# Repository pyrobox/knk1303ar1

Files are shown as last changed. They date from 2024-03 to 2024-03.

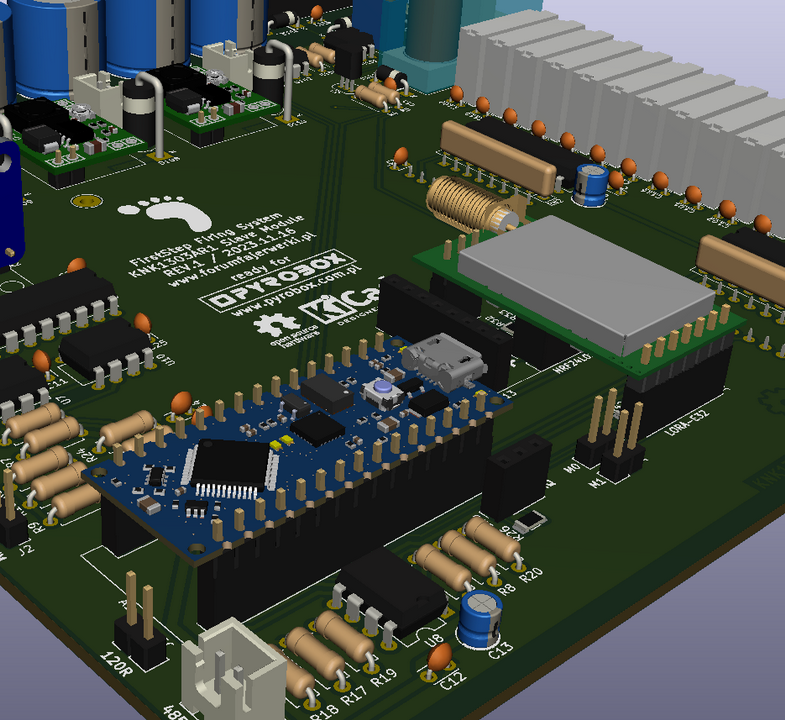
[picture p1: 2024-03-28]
img_20240310/KNK1303AR1_20240310_every_lora.png

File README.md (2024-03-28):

# KNK1303AR1

Project of firing module of amateur pyrotechnic system. 

## Description

For many years, the forum of fireworks enthusiasts https://forumfajerwerki.pl has been implementing projects of amateur pyrotechnic systems. 
KNK1303AR1 is another project, this time compatible with the professional Pyrobox pirotechnics system, based on the Arduino Nano Every board.
The design of the pcb was created in KiCad 7.0.8 and the code for Arduino Nano Every was written in Arduino IDE 2.3.2
This module is controlled by the free Pyrobox system software downloadable from https://www.pyrobox.com.pl/soft/downloads.html

## Help

You can find more information on the forumfajerwerki.pl in the thread 
https://www.forumfajerwerki.pl/topic/9585-forumowy-projekt-opensource-systemu-pirotechnicznego/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 
Forum registration is required.

A compendium of projects from the forumfajerwerki.pl
https://www.pyrobox.com.pl/knk1301/

## Authors

Zbigniew Kubicki (forumfajerwerki.pl nickname "zk1959")

## Version History

* Rev.1 as of 2024.03.10

## License

Open source hardware and freeware software.

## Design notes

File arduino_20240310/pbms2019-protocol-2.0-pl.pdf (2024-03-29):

PYROBOX Pyrotechnic Firing System | Data Transfer Protocol PBMS2019 Ver. 2.0

## PROTOKÓŁ TRANSMISJI DANYCH PBMS2019 Ver. 2.0

Protokół transmisji danych w systemie Pyrobox nie został z góry zaprojektowany lecz powstawał stopniowo (był poszerzany i modyfikowany z zachowaniem kompatybilności w dół) wraz z rozwojem systemu więc niektóre jego założenia i elementy są konsekwencją takiego właśnie procesu.

Sposób adresowania w systemie obwodów zapalczych (cue) także był modyfikowany i obecnie adresujemy je przez wskazanie kolejno:
G / group | zakres 1..16 | grupa urządzeń slave wykonujących określone (podobne) zadania
U / unit | zakres 1..16 | identyfikator urządzenia slave w grupie
M / module zakres 1..4 | numer modułu wykonawczego kontrolowanego przez urządzenie slave
S / section | zakres 1..16 | numer sekcji w module wykonawczym
C / channel zakres 1..16 | numer kanału w sekcji

Każdy program/kontroler master może więc nadzorować maksymalnie 16 grup urządzeń slave.
W każdej grupie może być maksymalnie 16 identyfikowanych urządzeń slave lub dowolna ich ilość jeśli zrezygnujemy z ich identyfikowania (co oznacza brak możliwości indywidualnego odwołania się do danego urządzenia np. zdalnego testowania obwodów zapalczych).
Każde urządzenie slave może nadzorować (obecnie) maksymalnie 4 moduły wykonawcze.
Moduł wykonawczy może mieć maksymalnie 16 sekcji, a każda sekcja ma 16 kanałów.
IP / max255 | G.U / max16.16 | M / max4 | S.C / max16.16

Urządzeniem slave może być:
- komputer z odpowiednim oprogramowaniem
- dedykowany konwerter np. konwerter/hab PB12CH4L1 obsługujący do 4 modułów
- moduł wykonawczy slave np. 32-kanałowy moduł SM032

Transmisja danych w sieci komunikacyjnej Pyrobox odbywa się w standardzie RS485. (https://pl.wikipedia.org/wiki/EIA-485)
Parametry transmisji: baudrate = 9600, bytesize = 8, parity = no, stopbits = 1, softflow = false, hardflow = false.
W transmisji mogą być wykorzystywane standardowe elementy sieci RS485 np. repeater, hub, radiomodem (transmisja przezroczysta).
Datasheet: pbms2019-protocol-2.0-pl.pdf | Page: 1 / 9

Master 1

Slave 1.2 | Section 1
Slave 1.1 | Module 1
| Module 2

Section 16

Master 2

Section 1

Section 16

PYROBOX Pyrotechnic Firing System | Data Transfer Protocol PBMS2019 Ver. 2.0

Dane przesyłane są w postaci ciągu znaków ASCII.
Ciąg znaków zawiera kolejno:
- znak „{” oznaczający początek pakietu danych (start)
- 4 znaki sumy kontrolnej CRC16 CCITT X-MODEM, oznaczane dalej jako <crc>
- 2 znaki literowe oznaczające komendę/rozkaz, dalej <cmd>
- 2 znaki z zakresu 00..FF wskazujące część adresu obwodu zapalczego Group.Unit , dalej <adr>
- 2 znaki z zakresu 00..03 wskazujące kolejną część adresu Module, dalej <mod>
- 2 znaki z zakresu 00..FF wskazujące kolejną część adresu Section.Channel, dalej <cue>
- n znaków danych sformatowanych w sposób przedstawiony w tabelach poniżej
- znak „}” oznaczający koniec pakietu (stop)
W przypadku niektórych komend część z wymienionych elementów ciągu nie jest wykorzystywana.

Komendy podzielone zostały na 3 grupy:
- grupa 1 - rozkazy kierowane jednocześnie do wszystkich urządzeń
- grupa 2 - rozkazy kierowane do jednego lub wszystkich urządzeń w grupie
- grupa 3 - rozkazy kierowane tylko do jednego urządzenia w grupie
Datasheet: pbms2019-protocol-2.0-pl.pdf | Page: 2 / 9

PYROBOX Pyrotechnic Firing System | PBMS2019 Data Transfer Protocol Ver. 2.0

GROUP 1 / All Units, part 1

COMMANDS: | 1 | 2 | 3 | 4 | 5 | 6 | 7 | 8 | 9 | 10 | 11 | chars | string | answer
MN Arm_On_All | { | <crc> | MN | } | | | | | | | | 8 | {D29AMN)
MN Arm_On_Unit_PBMS2019 | { | <crc> | MN | <adr> | } | | | | | | | 10
MF Arm_Off_All | { | <crc> | MF | } | | | | | | | | 8 | (5392MF}
MF Arm_Off_Unit_PBMS2019 | { | <crc> | MF | <adr> | } | | | | | | | 10
MR Reset_All | { | <crc> | MR | } | | | | | | | | 8 | {0127MR}
MR Reset_Unit_PBMS2019 | { | <crc> | MR | <adr> | } | | | | | | | 10
XP | HeartBeat | { | <crc> | XP | } | 8 | {DDE3XP}
XM Start (sfx: time) | { | <crc> | XM | } | | | | | | | | 8 | {1E7FXM}
XT | Message (sfx: txt=str) | { | <crc> | XT | <txt> | } | max29
FA | All_Slave_Units (sfx: all=xxx) | { | <crc> | FA | <all> | } | 11
MX SAM_Start_PBMS2019v2.0 | { | <crc> | MX | <hms> | } | | | | | | | 14
MY SAM_Stop_PBMS2019v2.0 | { | <crc> | MY | } | | | | | | | | 8 | {B04CMY}
MZ SAM_HeartBeat_PBMS2019v2.0 | { | <crc> | MZ | } | | | | | | | | 8 | {802FMZ}
WA Warning_Ready_PBMS2019v2.0 | { | <crc> | WA | } | | | | | | | | 8 | {CFCDWA}
WB Warning_Armed_PBMS2019v2.0 | { | <crc> | WB | } | | | | | | | | 8 | {FFAEWB}
WC Warning_Disarmed_PBMS2019v2.0 | { | <crc> | WC | } | | | | | | | | 8 | {EF8FWC}
WD Warning_Safe_PBMS2019v2.0 | { | <crc> | WD | } | | | | | | | | 8 | {9F68WD}
MN | uzbroić system / uzbroić urządzenie <adr>
MF | rozbroić system / rozbroić urządzenie <adr>
MR | zresetować system / zresetować urządzenie <adr>
XP | sygnał heartbeat
XM | sygnał start | → funkcja: time
XT | wiadomość tekstowa | → funkcja: txt=str | → <txt>max21 / x..z | ← x..z = max 21 chars
FA | wykonać zadanie xxx ze skryptu ASU | → funkcja: all=xxx | → <all>3 / xxx | ← xxx = 001...999 number
MX | sygnał start w trybie SAM | → <hms>6 / hhmmss | ← hh=00..23 „hour” / mm=00..59 „minute” / ss=00..59 „second”
MY | awaryjny sygnał stop w trybie SAM | → Death Man Switch
MZ | sygnał heartbeat w trybie SAM | → max every 4.5sec
WA | pokazać że urządzenie jest w gotowości / manual | → yellow signal ligth
WB | pokazać że urządzenie jest uzbrojone / auto 1sec after MN | → red signal light
WC | pokazać że urządzenie jest rozbrojone / auto 1sec after MF | → green signal light
WD | pokazać że urządzenie jest bezpieczne / manual | → blue signal light
Datasheet: pbms2019-protocol-2.0-pl.pdf | Page: 3 / 9

PYROBOX Pyrotechnic Firing System | PBMS2019 Data Transfer Protocol Ver. 2.0

GROUP 1 / All Units, part 2 PBMS2019

COMMANDS: | 1 | 2 | 3 | 4 | 5 | 6 | 7 | 8 | 9 | 10 | 11 | chars | string | answer
SERVICE MODE ONLY:
PS | Write_IDNO | { | <crc> | PS | <ser> | } | 17 | yes
PS | Write_IDNO_check | { | <crc> | PS | <ser> | } | 17
NORMAL MODE:
PX | Read_IDNO | { | <crc> | PX | } | 8 | {D542PX} | yes
PX | Read_IDNO_answer | { | <crc> | PX | <ser> | } | 17
PY | Read_USER | { | <crc> | PY | <ser> | } | 17 | yes
PY | Read_USER_answer | { | <crc> | PY | <ser> | <usr> | } | 26
PU Write_USER | { | <crc> | PU | <ser> | <usr> | } | | | | | | 26 | | yes
PU Write_USER_check | { | <crc> | PU | <ser> | <usr> | } | | | | | | 26
PZ | Read_ADDR | { | <crc> | PZ | <ser> | } | 17 | yes
PZ | Read_ADDR_answer | { | <crc> | PZ | <ser> | <add> | } | 23
PA | Write_ADDR | { | <crc> | PA | <ser> | <add> | } | 23 | yes
PA | Write_ADDR_check | { | <crc> | PA | <ser> | <add> | } | 23
PD Read_DATA | { | <crc> | PD | <ser> | } | | | | | | | 17 | | yes
PD Read_DATA_answer | { | <crc> | PD | <inf> | <pwr> | <ser> | <usr> | <add> <arm> | <ant> | } | max46
PS | zapisać numer seryjny urządzenia | → <ser>9 / xxxxyynnn | ← xxxx=ABcd „type” / yy=19..99 „year” / nnn=001..999 „ser#”
PX | przesłać numer seryjny urządzenia
PY | przesłać identyfikator urządzenia | → <usr>9 / xxxyyynnn | ← xxx=ABC „user” / yyy=ABC „tool” / nnn=001..999 „idn#”
PU | zapisać identyfikator urządzenia
PZ | przesłać adres konfiguracyjny urządzenia | → <add>6 / xgumsc | ← x=2..5 / g=0..F / u=0..F / m=0..3 / s=0..F / c=0,4,8,C
PA | zapisać adres konfiguracyjny urządzenia
PD | przesłać pełną informację nt. Urządzenia | → <inf>4 / xxxx | ← x=0,1,2,3,7,B,F number of sections 0,2,3,4,8,12,16
→ <pwr>6 / xxxyyy | ← xxx=000..360 pwr#1 inside / yyy=000..500 pwr#2 outside
→ <arm>1 / x = 0..3 | ← 0=safe / hard_arm=0/1 / soft_arm=0/2 / 3=armed
→ <ant>3 / xxx = 000..100 ← % RF signal power
Datasheet: pbms2019-protocol-2.0-pl.pdf | Page: 4 / 9

PYROBOX Pyrotechnic Firing System | PBMS2019 Data Transfer Protocol Ver. 2.0

GROUP 2 / All Or One Unit In Group

COMMANDS: | 1 | 2 | 3 | 4 | 5 | 6 | 7 | 8 | 9 | 10 | 11 | chars | string | answer
FC | Fire_Cue_G | { | <crc> | FC | <adr> <mod> <cue> | } | 14
FO Fire_Cue_U (sfx: one=nn) | { | <crc> | FO | <adr> <mod> <cue> <one> | } | 15
FP | Fire_Pulse_G (sfx: imp=xxx) | { | <crc> | FP | <adr> <mod> <cue> | <pls> | } | 17
FP | Fire_Pulse_U (sfx: imp=xxx/nn) | { | <crc> | FP | <adr> <mod> <cue> | <pls> | <one> | } | 18
FS | Regular_Sequencer_G (sfx: seq=aa/bb) | { | <crc> | FS | <adr> <mod> <cue> | <ssn> | <sst> | } | 18
FS | Regular_Sequencer_U (sfx: seq=aa/bb/nn) | { | <crc> | FS | <adr> <mod> <cue> | <ssn> | <sst> | <one> | } | 19
FH | Speed_Up_Sequencer_G (sfx: shi=aa/bb/cc) | { | <crc> | FH | <adr> <mod> <cue> | <ssn> | <sst> | <ssd> | } | 20
FH | Speed_Up_Sequencer_U (sfx: shi=aa/bb/cc/nn) | { | <crc> | FH | <adr> <mod> <cue> | <ssn> | <sst> | <ssd> <one> | } | 21
FL | Speed_Down_Sequencer_G (sfx: slo=aa/bb/cc) | { | <crc> | FL | <adr> <mod> <cue> | <ssn> | <sst> | <ssd> | } | 20
FL | Speed_Down_Sequencer_U (sfx: slo=aa/bb/cc/nn) | { | <crc> | FL | <adr> <mod> <cue> | <ssn> | <sst> | <ssd> <one> | } | 21
FT | Programming_Sequencer_G (sfx: sdf=xxx) | { | <crc> | FT | <adr> | <sdf> | } | 14
FT | Programming_Sequencer_U (sfx: sdf=xxx/nn) | { | <crc> | FT | <adr> | <sdf> | <one> | } | 14
FN | Zero_Delay_Firing_G (sfx: nxt=x, x=2..5) | { | <crc> | FN | <adr> <mod> <cue> | .. | <adr5> <mod5> <cue5> | } | max38
MS Set_Select_Cues_G (sfx: set=xxxxxxxx) | { | <crc> | MS | <adr> <mod> <set> | } | 20
MS Set_Select_Cues_U (sfx: set=xxxxxxxx/nn) | { | <crc> | MS | <adr> <mod> <set> | <one> | } | 21
FC | odpalić cue w grupie
FO | odpalić cue w urządzeniu <one> | → funkcja: one=nn | → <one>2 / nn = 01..16 unit#
FP | odpalić cue impulsem xxx | → funkcja: imp=xxx/nn | → <pls>3 / xxx = 100..900 msec ++ nn = 01..16 „one”
FS | uruchomić sekwencję | → funkcja: seq=aa/bb/nn | → <ssn>2 / aa = 02..99 ++ <sst>2 / bb = 02..99 ++ nn = 01..16 „one”
FH | uruchomić sekwencję step-up | → funkcja: shi=aa/bb/cc/nn | → <ssn>2 / aa = 02..99 ++ <sst>2 / bb = 02..99 ++ <ssd>2 / cc = 01..49 ++ nn = 01..16
FL | uruchomić sekwencję step-down | → funkcja: slo=aa/bb/cc/nn | → <ssn>2 / aa = 02..99 ++ <sst>2 / bb = 02..99 ++ <ssd>2 / cc = 01..49 ++ nn = 01..16
FT | uruchomić sekwencję ze skryptu SDF | → funkcja: sdf=xxx/nn | → <sdf>3 / xxx = 001..999 ++ nn = 01..16 „one”
FN | odpalić x cue w grupie | → funkcja: nxt=x | → x = 2..5 repeats <adr><mod><cue>
MS | włączyć y cue w urządzeniu | → funkcja: set=xxxxxxxx/nn → <set>8 / xxxxxxxx = 00000000..FFFFFFFF ++ nn = 01..16 „one”
Datasheet: pbms2019-protocol-2.0-pl.pdf | Page: 5 / 9

PYROBOX Pyrotechnic Firing System | PBMS2019 Data Transfer Protocol Ver. 2.0

GROUP 3 / One Unit In Group, part 1

COMMANDS: | 1 | 2 | 3 | 4 | 5 | 6 | 7 | 8 | 9 | 10 | 11 | chars | string | answer
XY | Master_Slave_Link_Test | { | <crc> | XY | <adr> | } | 10 | yes
XY | MSLT_answer | { | <crc> | XY | <adr> | <inf> | <pwr> | } | 14/20
XY | MSLT_answer_PBMS2019 | { | <crc> | YX | <adr> | <ser> | } | 19
YX | Slave_Master_Link_Test | { | <crc> | YX | <adr> | } | 10 | yes
YX | SMLT_answer | { | <crc> | YX | <adr> | } | 10
YX | Slave_Master_Link_Test_PBMS2019 | { | <crc> | YX | <adr> | <ser> | } | 19 | yes
YX | SMLT_answer_PBMS2019 | { | <crc> | YX | <adr> | <ser> | } | 19
XZ | Master_Reserve_Link_Test | { | <crc> | XZ | } | 8 | {7CA9XZ} | yes
XZ | MRLT_answer | { | <crc> | XZ | } | 8 | {7CA9XZ}
XZ | MRLT_answer_PBMS2019 | { | <crc> | XZ | <ser> | } | 17
ZX | Reserve_Master_Link_Test | { | <crc> | ZX | } | 8 | {3A89ZX} | yes
ZX | RMLT_answer | { | <crc> | ZX | } | 8 | {3A89ZX}
ZX | RMLT_answer_PBMS2019 | { | <crc> | ZX | <ser> | } | 17
ZZ | Master_Reserve_Switch | { | <crc> | ZZ | } | 8 | (1ACBZZ}
XY | sprawdzić połączenie master → slave <adr>
YX | sprawdzić połączenie slave <adr> → master
XZ | sprawdzić połączenie master → master_reserve
ZX | sprawdzić połączenie master_reserve → master
ZZ | przekazać kontrolę master → reserve master
Datasheet: pbms2019-protocol-2.0-pl.pdf | Page: 6 / 9

PYROBOX Pyrotechnic Firing System | PBMS2019 Data Transfer Protocol Ver. 2.0

GROUP 3 / One Unit In Group, part 2 PBMS2019v2.0

COMMANDS: | 1 | 2 | 3 | 4 | 5 | 6 | 7 | 8 | 9 | 10 | 11 | chars | string | answer
XK Master_Keypad_Link_Test | { | <crc> | XK | } | | | | | | | | 8 | {7EB9XK} | yes
XK MKLT_answer | { | <crc> | XK | } | | | | | | | | 8 | {7EB9XK}
XK MKLT_answer_PBMS2019v2.0 | { | <crc> | XK | <ser> | } | | | | | | | 17
KX Keypad_Master_Link_Test | { | <crc> | KX | } | | | | | | | | 8 | {0ACBKX} | yes
KX KMLT_answer | { | <crc> | KX | } | | | | | | | | 8 | {0ACBKX}
KX KMLT_answer_PBM2019v2.0 | { | <crc> | KX | <ser> | } | | | | | | | 17
XV | Master_Starter_Link_Test | { | <crc> | XV | } | 8 | {DB25XV} | yes
XV | MSLT_answer | { | <crc> | XV | } | 8 | {DB25XV}
XV | MSLT_answer_PBMS2019v2.0 | { | <crc> | XV | <ser> | } | 17
VX | Starter_Master_Link_Test | { | <crc> | VX | } | 8 | {7FE4VX} | yes
VX | SMLT_answer | { | <crc> | VX | } | 8 | {7FE4VX}
VX | SMLT_answer_PBMS2019v2.0 | { | <crc> | VX | <ser> | } | 17
XK | sprawdzić połączenie master → keypad
KX | sprawdzić połączenie keypad → master
XV | sprawdzić połączenie master → starter
VX | sprawdzić połączenie starter → master
Datasheet: pbms2019-protocol-2.0-pl.pdf | Page: 7 / 9

PYROBOX Pyrotechnic Firing System | PBMS2019 Data Transfer Protocol Ver. 2.0

GROUP 3 / One Unit In Group, part 3

COMMANDS: | 1 | 2 | 3 | 4 | 5 | 6 | 7 | 8 | 9 | 10 | 11 | chars | string | answer
XA | Master_Player_Link_Test | { | <crc> | XA | } | 8 | {DFF3XA} | yes
XA | MPLT_answer | { | <crc> | XA | } | 8 | {DFF3XA}
XA | MPLT_answer_PBMS2019 | { | <crc> | XA | <ser> | } | 17
AX | Player_Master_Link_Test | { | <crc> | AX | } | 8 | {E500AX} | yes
AX | PMLT_answer | { | <crc> | AX | } | 8 | {E500AX}
AX | Player_Master_Link_Test_PBMS2019 | { | <crc> | AX | <ser> | } | 17 | yes
AX | PMLT_answer_PBMS2019 | { | <crc> | AX | <ser> | } | 17
XB | Master_Player_Reserve_Link_Test | { | <crc> | XB | } | 8 | {EF90XB} | yes
XB | MPRLT_answer | { | <crc> | XB | } | 8 | {EF90XB}
XB | MPRLT_answer_PBMS2019 | { | <crc> | XB | <ser> | } | 17
BX | Player_Reserve_Master_Link_Test | { | <crc> | BX | } | 8 | {B053BX} | yes
BX | PRMLT_answer | { | <crc> | BX | } | 8 | {B053BX}
BX | Player_Reserve_Master_Link_Test_PBMS2019 | { | <crc> | BX | <ser> | } | 17 | yes
BX | PRMLT_answer_PBMS2019 | { | <crc> | BX | <ser> | } | 17
XA | sprawdzić połączenie master → player
AX | sprawdzić połączenie player → master
XB | sprawdzić połączenie master → reserve player
BX | sprawdzić połączenie reserve player → master
Datasheet: pbms2019-protocol-2.0-pl.pdf | Page: 8 / 9

PYROBOX Pyrotechnic Firing System | PBMS2019 Data Transfer Protocol Ver. 2.0

GROUP 3 / One Unit In Group, part 4

COMMANDS: | 1 | 2 | 3 | 4 | 5 | 6 | 7 | 8 | 9 | 10 | 11 | chars | string | answer
TC | Test_Cue | { | <crc> | TC | <adr> <mod> <cue> | } | 14
TS | Test_Section | { | <crc> | TS | <adr> <mod> <cue> | } | 14
TM Test_Module | { | <crc> | TM | <adr> <mod> <cue> | } | 14
SC Send_Test_Cue | { | <crc> | SC | <adr> | } | | | | | | | 10 | | yes
SC STC_answer | { | <crc> | SC | <adr> | <0/1> | } | | | | | | 11
SS | Send_Test_Section | { | <crc> | SS | <adr> | } | 10 | yes
SS | STS_answer | { | <crc> | SS | <adr> | <tds> | } | 14
SM Send_Test_Module | { | <crc> | SM | <adr> | } | | | | | | | 10 | | yes
SM STM_answer | { | <crc> | SM | <adr> | <tdp> | <tdm> | } | | | | | 1..4x28
TC | wykonać test cue
TS | wykonać test całej sekcji
TM | wykonać test całego modułu
SC | przesłać wyniki testu cue | → <0/1>1 = 0/1
SS | przesłać wyniki testu sekcji | → <tds>4 = 0000..FFFF
SM | przesłać wyniki testu modułu | → <tdp>2 = 00..11 packet# / <tdm>16 = 0000000000000000..FFFFFFFFFFFFFFFF
Datasheet: pbms2019-protocol-2.0-pl.pdf | Page: 9 / 9

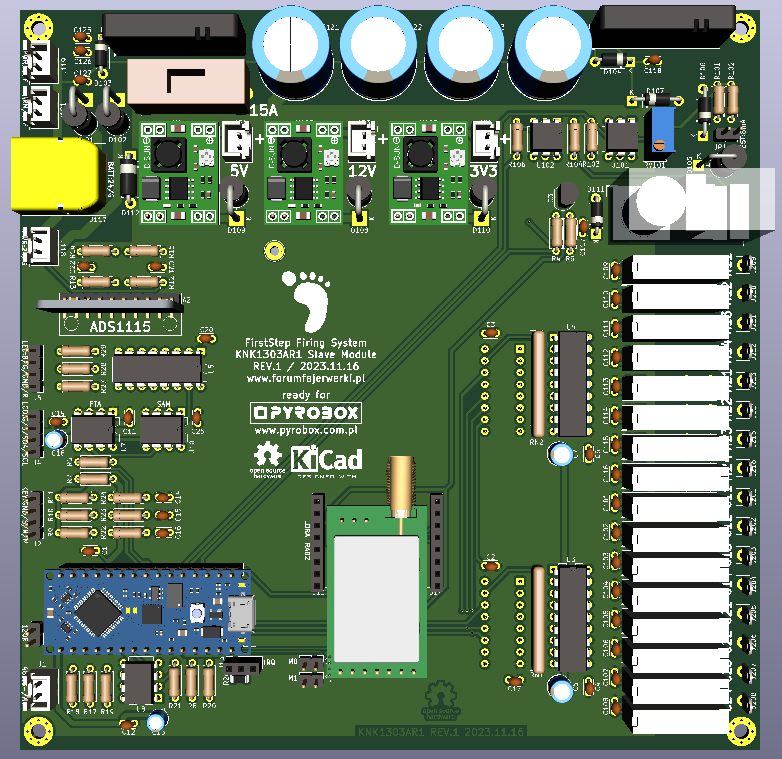
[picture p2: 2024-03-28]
img_20240310/KNK1303AR1_20240310_top.png

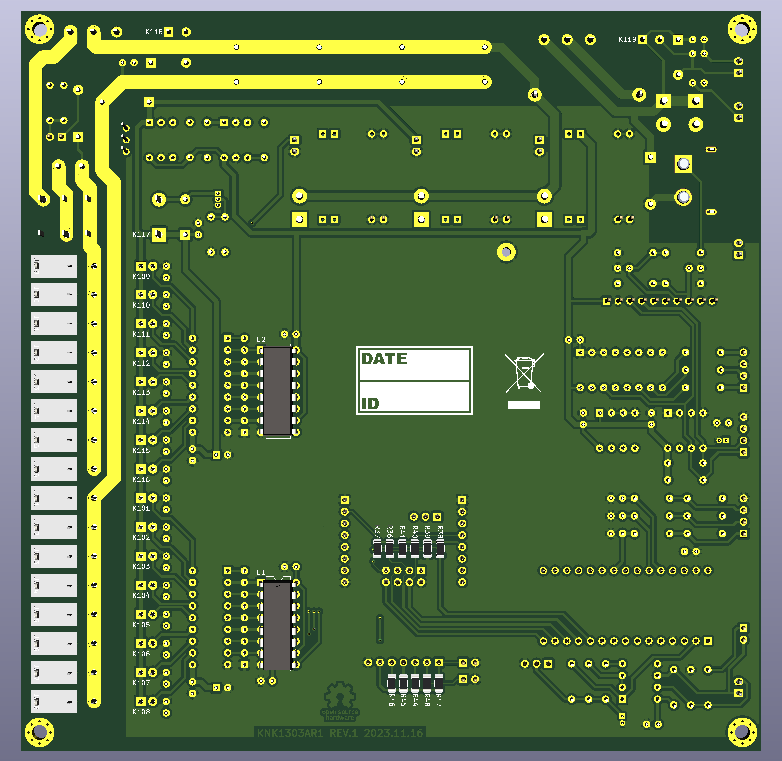
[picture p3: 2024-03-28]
img_20240310/KNK1303AR1_20240310_bottom.png

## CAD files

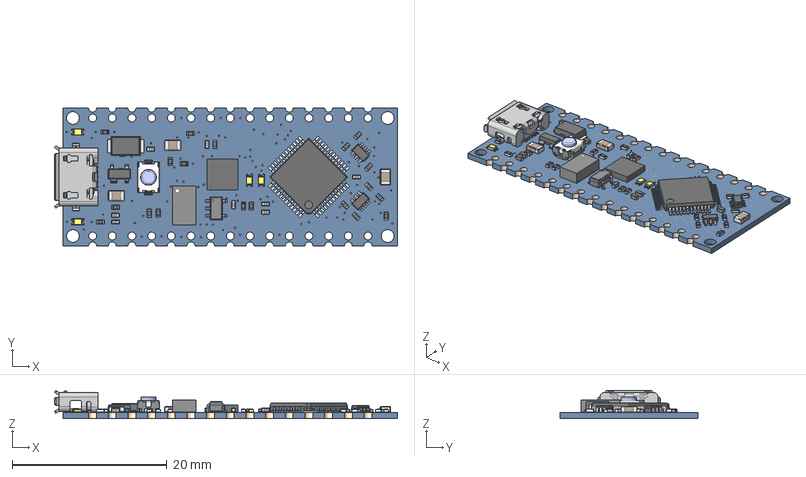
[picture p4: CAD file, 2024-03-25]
kicad_20240310/project_KNK1303AR1_3d/pyrobox_module_NANO_EVERY_v30.step
44.3 x 17.8 x 3.62 mm
Board
DNP x 19
22u x 3
PTS820
YELLOW x 4
MPM3610
AP2112K-3.3
ATSAMD11D14A
ATMEGA4809
ZX62-AB-5PA (1)
SOD128 Lead x 2
SOD128 Lower body x 2
SOD128 Upper body x 2
SOT143B lower body
SOT143B small Lead x 3
SOT143B Large lead
SOT143B Upper body
SOT353 Lower body x 2
SOT353 Lead x 12
SOT353 Upper body x 2
CAPC-0402-T0.55-BN v1 x 8

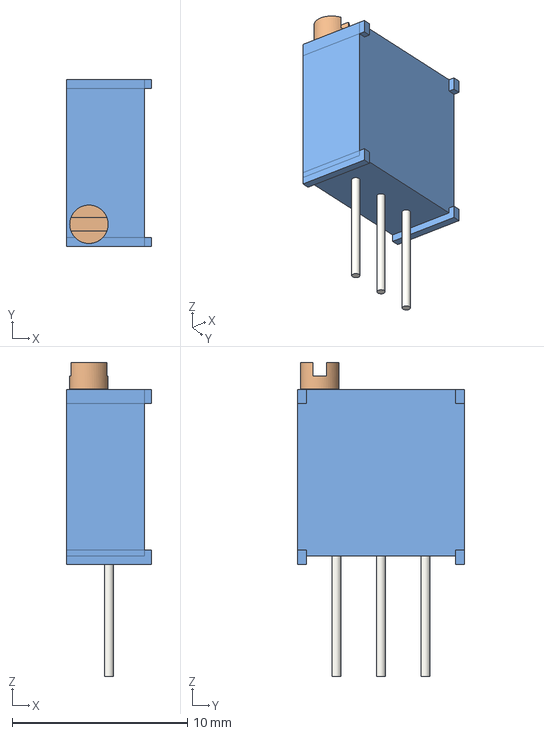
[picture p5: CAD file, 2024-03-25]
kicad_20240310/project_KNK1303AR1_3d/pyrobox_pcs_BOURNS-3296W.step
4.83 x 9.53 x 17.9 mm

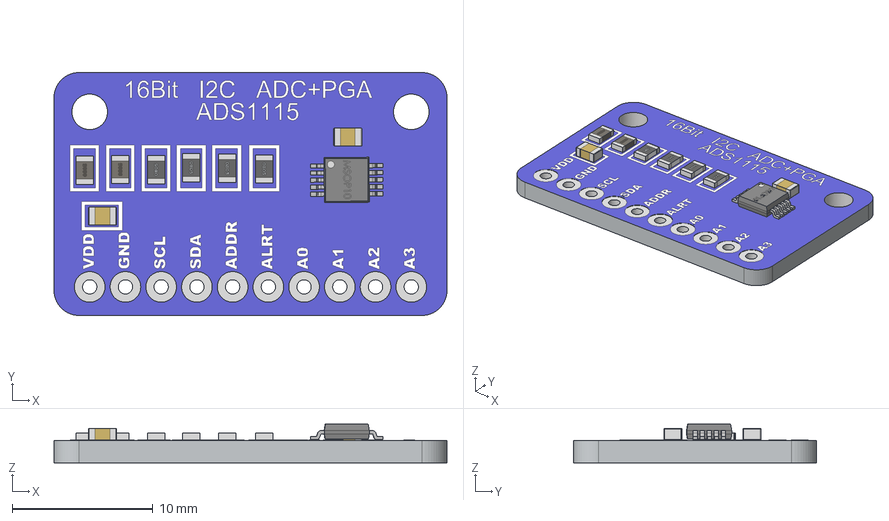
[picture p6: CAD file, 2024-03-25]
kicad_20240310/project_KNK1303AR1_3d/pyrobox_module_ADS1115.stp
27.9 x 17.3 x 2.74 mm
ADS1115
0805 Capacitor x 2
0805 Inductor x 2
0805 Resistor x 4
MSOP10

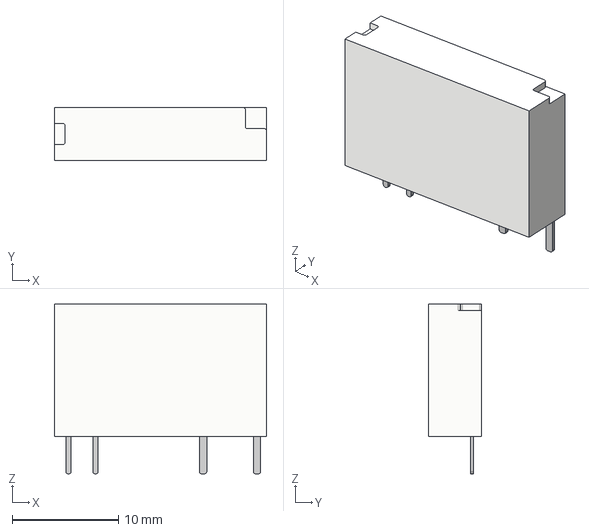
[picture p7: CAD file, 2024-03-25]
kicad_20240310/project_KNK1303AR1_3d/pyrobox_pcs_HONGFA_HF49FD-1H11T.step
20.0 x 5.00 x 16.0 mm

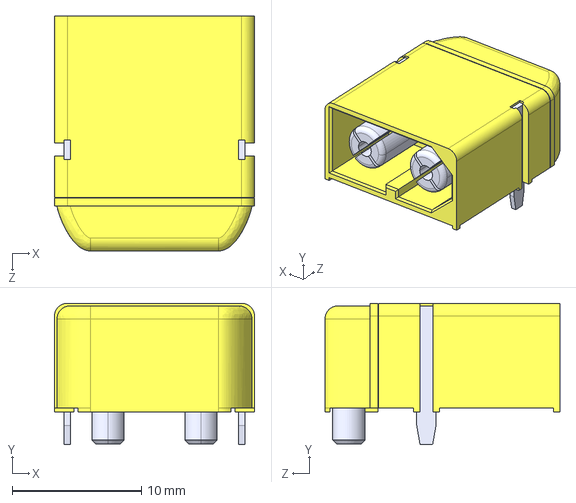
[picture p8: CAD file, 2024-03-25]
kicad_20240310/project_KNK1303AR1_3d/pyrobox_pcs_AMASS_XT60PW-M.step
15.5 x 11.0 x 18.2 mm

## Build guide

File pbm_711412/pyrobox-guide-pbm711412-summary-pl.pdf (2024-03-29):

PYROBOX Pyrotechnic Firing System | USER GUIDE | Pyrobox Controller MS Master PBM

Pyrobox Controller MS Master PBM Copyright © 2004-2024 Zbigniew Kubicki Pyrobox Pyrotechnic Firing System Copyright © 1994-2024 Zbigniew Kubicki

## Pyrobox Controller MS Master PBM, Version 7.1.1.412 USER GUIDE (summary)

Copyright © 2023-2024 Zbigniew Kubicki (Grupa PSO | K&K System)

## SPIS TREŚCI

Formatka Main | . | . | . | . | . | . | . | . | . | . | . | . | . | . | strona 2
Formatka Info+Update | . | . | . | . | . | . | . | . | . | . | . | strona 2

### A. SETUP

A1. Formatka SETUP . | . | . | . | . | . | . | . | . | . | . | . | . | . | strona 3
Grupa Access | . | . | . | . | . | . | . | . | . | . | . | . | . | strona 3
Grupa NET Starter | . | . | . | . | . | . | . | . | . | . | . | . | strona 3
Grupa DMX Starter | . | . | . | . | . | . | . | . | . | . | . | . | strona 4
Grupa OS Date/Time | SAM Mode . | . | . | . | . | . | . | . | . | strona 4
A2. Formatka NETWORK . | . | . | . | . | . | . | . | . | . | . | . | . | strona 4
Formatka DEVICE SETUP . | . | . | . | . | . | . | . | . | . | . | strona 5
Formatka NETWORK MONITOR | . | . | . | . | . | . | . | . | . | strona 5
Formatka MONITOR . | . | . | . | . | . | . | . | . | . | . | . | strona 6
A3. Formatka TESTER | . | . | . | . | . | . | . | . | . | . | . | . | . | strona 6
Formatka Test Result . | . | . | . | . | . | . | . | . | . | . | . | strona 7

### B. AUTO CONTROL

B1. Formatka EDITOR | . | . | . | . | . | . | . | . | . | . | . | . | . | strona 8
Formatka SPECIAL FUNCTIONS | . | . | . | . | . | . | . | . | . | strona 9
Funkcje specjalne | . | . | . | . | . | . | . | . | . | . | . | . | strona 9
Formatka SAM SCRIPT GENERATOR . | . | . | . | . | . | . | . | strona 10
B2. Formatka PLAYER | . | . | . | . | . | . | . | . | . | . | . | . | . | strona 10
B3. Formatka STEPPER . | . | . | . | . | . | . | . | . | . | . | . | . | strona 11
Formatka DELAY | . | . | . | . | . | . | . | . | . | . | . | . | strona 11
Formatka RESERVE . | . | . | . | . | . | . | . | . | . | . | . | strona 11
Formatka EXPLO X2 WAVE FLAMER Setup | . | . | . | . | . | . | strona 12
Formatka SAM Setup . | . | . | . | . | . | . | . | . | . | . | . | strona 12

### C. MANUAL CONTROL

C1. Formatka PBM | . | . | . | . | . | . | . | . | . | . | . | . | . | . | strona 13
C2. Formatka PBM STAGE | . | . | . | . | . | . | . | . | . | . | . | . | strona 13
Formatka PBM STAGE SETUP | . | . | . | . | . | . | . | . | . | strona 14
C3. Formatka DMX | . | . | . | . | . | . | . | . | . | . | . | . | . | . | strona 14
C4. Formatka DMX STAGE | . | . | . | . | . | . | . | . | . | . | . | . | strona 15
Formatka DMX STAGE SETUP | . | . | . | . | . | . | . | . | . | strona 15

### D. FIRST STEPS

D1. Instalacja i konfiguracja programu | . | . | . | . | . | . | . | . | . | . | strona 16
D2. Przygotowania i realizacja widowiska | . | . | . | . | . | . | . | . | . | strona 16
D3. Podpowiedzi i pomoce | . | . | . | . | . | . | . | . | . | . | . | . | strona 17
D4. System rozległy Pyrobox | . | . | . | . | . | . | . | . | . | . | . | . | strona 18
Datasheet: pyrobox-guide-pbm711412-summary-pl.pdf | Page: 1 / 18

### Formatka MAIN

1. Logo PYROBOX – kliknięcie otwiera formatkę INFO+UPDATE
2. Kontrolka Heart – sygnalizuje wysłanie/odebranie z sieci systemu sygnału „heartbeat”
3. Kontrolka PC – sygnalizuje odebranie z sieci NET systemu sygnału „ping”
4. Przycisk Setup – otwiera/zamyka formatkę SETUP
5. Przycisk Network – otwiera/zamyka formatkę NETWORK
6. Przycisk Tester – otwiera/zamyka formatkę TESTER
7. Przycisk Stepper – otwiera/zamyka formatkę STEPPER
8. Przycisk Player – otwiera/zamyka formatkę PLAYER
9. Przycisk Editor – otwiera/zamyka formatkę EDITOR
10. Przycisk DMX – otwiera/zamyka formatkę DMX
11. Przycisk DMX Stage – otwiera/zamyka formatkę DMX STAGE
12. Przycisk PBM – otwiera/zamyka formatkę PBM
13. Przycisk PBM Stage – otwiera/zamyka formatkę PBM STAGE
14. Przycisk Power – zamyka aplikację
15. Dolna belka formatki – po lewej wyświetla datę i czas, na środku i po prawej komunikaty
16. Formatka INFO+UPDATE
- przycisk Update – uruchamia procedurę pobierania aktualizacji programu

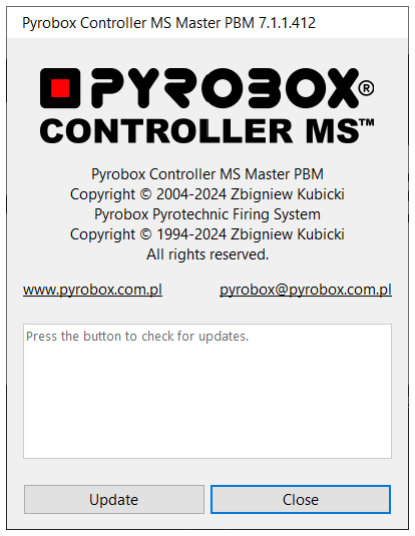
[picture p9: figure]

Uwaga!
Ogólne zasady pracy z programem Pyrobox Controller MS Master PBM zostały opisane w części D na stronie 16
Datasheet: pyrobox-guide-pbm711412-summary-pl.pdf | Page: 2 / 18

## A. SETUP

### A1. Formatka SETUP

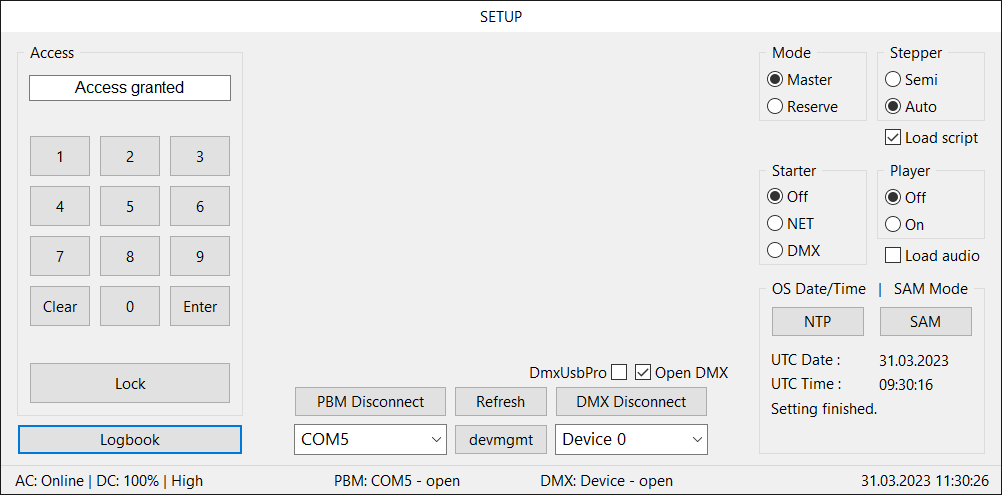
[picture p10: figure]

1. Grupa Access – służy do wprowadzania kodu dostępu, aktywuje krytyczne funkcje programu
- standardowy kod to "1234", zmieniamy go wprowadzając 4 cyfry starego i 4 cyfry nowego kodu
- przyciski 0..9, Clear oraz Enter spełniają standardowe funkcje
- przycisk Lock – anuluje uzyskaną autoryzację, ogranicza dostęp do krytycznych funkcji programu
2. Przycisk Logbook(Access) – przełącza widok pomiędzy grupami Access i Logbook
3. Grupa Logbook – udostępnia podgląd rejestru wykonanych czynności, oraz rejestrów wysłanych i odebranych komend/informacji
- przycisk Next – przełącza rejestry
- przycisk Open – otwiera folder zapisanych rejestrów
4. Przycisk PBM Connect/Disconnect + lista wyboru – włącza/wyłącza port PBM (USB/RS485)
5. Przycisk DMX Connect/Disconnect + lista wyboru – włącza/wyłącza port DMX (USB/DMX512)
6. Klucz DmxPro – włącza obsługę konwertera typu DMX USB PRO, a wyłącza OPEN USB DMX
7. Klucz Open DMX – włącza/wyłącza automatyczne otwieranie portu DMX
8. Przycisk Refresh – aktualizuje listy wyboru portów PBM, DMX oraz DMX Sterter
9. Przycisk devmgmt – otwiera formatkę systemową „Menadżer urządzeń”
10. Grupa Mode – ustawia tryb pracy programu: Master lub Reserve
11. Grupa Stepper – ustawia tryb pracy Steppera: Semi lub Auto
12. Klucz Load script – włącza/wyłącza automatyczne ładowanie skryptu do Steppera
13. Grupa Player – dołącza/odłącza Playera od Steppera
14. Klucz Load audio – włącza/wyłącza automatyczne ładowanie pliku audio do Playera
15. Grupa Starter – wyświetla odpowiednio grupy NET Starter lub DMX Starter
16. dolna belka – po lewej wyświetlana jest informacja o zasilaniu komputera, na środku o portach COM PBM i DMX, a po prawej data/czas
17. Grupa NET Starter – przechwytuje sygnał startu wysłany z serwera „NET Starter” pracującego w „prywatnej” sieci LAN np. Hamachi (aplikacja VPN - Virtual Private Network)
Datasheet: pyrobox-guide-pbm711412-summary-pl.pdf | Page: 3 / 18

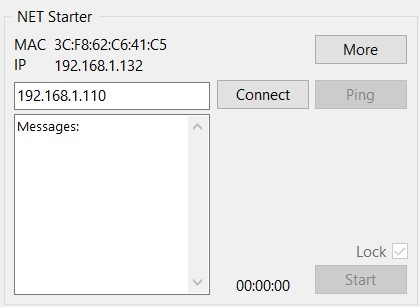
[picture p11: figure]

- etykieta MAC – adres sprzętowy karty sieciowej komputera
- etykieta IP – adres sieciowy komputera
- przycisk More – pobiera z komputera i wyświetla informacje „Primary Adapter Info”
- pole edycji Server – zawiera adres sieciowy serwera „NET Starter”
- przycisk Connect – nawiązuje połączenie z serwerem „NET Starter”
- przycisk Ping – wysyła ping do serwera „NET Starter” (test połączenia)
- przycisk Start – uruchamia NET Starter (oczekiwanie na komendę „start”)
18. Grupa DMX Starter – przechwytuje ustalony sygnał startu wysłany z kontrolera DMX lub innego (np. Art-Net) z konwersją transmisji na standard DMX
- pole wyboru Address – ustawia adres pierwszego z czterech kolejnych kanałów „triggera”
- pola wyboru Value – ustawiają wartości kanałów, a klucze dołączają kanały do „triggera”
- przycisk Connect/Disconnect + lista wyboru – włącza/wyłącza port DMX (USB/DMX512)
- przycisk Start – uruchamia DMX Starter (oczekiwanie na komendę „start”)

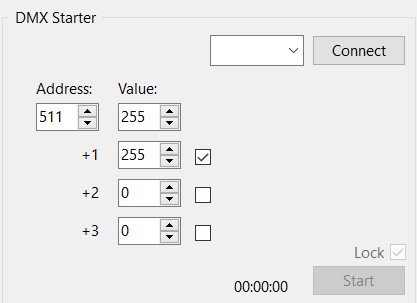
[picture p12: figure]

19. Grupa OS Date/Time | SAM Mode – obsługa trybu pracy SAM (Slave Autonomic Mode)
- przycisk NTP – uruchamia proces synchronizacji czasu systemowego komputera z serwerem NTP (Network Time Protocol) co jest niezbędne do pracy systemu w trybie SAM
- przycisk SAM – otwiera/zamyka formatkę SAM Setup opisaną na stronie 12

### A2. Formatka NETWORK

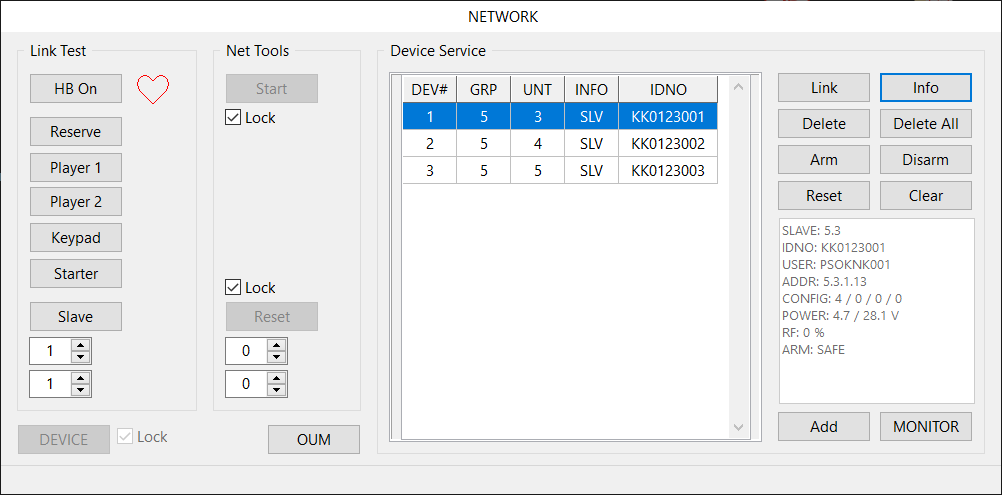
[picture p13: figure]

1. Grupa Link Test – umożliwia kontrolę pracy sieci systemu
- przycisk HB On – włącza/wyłącza sygnał „heartbeat”
- kontrolka Heart – sygnalizuje generowany sygnał „heartbeat”
- przycisk Reserve – testuje połączenie z Master-Reserve
- przycisk Player 1 - testuje połączenie z Player
- przycisk Player 2 - testuje połączenie z Player-Reserve
- przycisk Keypad – testuje połączenie z Master-Keypad
- przycisk Starter – testuje połączenie z Starter
- przycisk Slave - testuje połączenia z urządzeniem o adresie jak w polach wyboru (group+unit)
Datasheet: pyrobox-guide-pbm711412-summary-pl.pdf | Page: 4 / 18

2. Grupa Net Tools – pozwala wysyłać systemowe komendy:
- przycisk Start – wysyła komendę „start”
- przycisk Reset – wysyła komendę „reset” do urządzenia o adresie jak w polach wyboru (group+unit), 0 oznacza wszystkie grupy/jednostki
3. Grupa Device Service – służy do kontroli pracy urządzeń w sieci systemu
Uwaga! część z funkcji w tej grupie realizują wyłącznie urządzenia obsługujące protokół PBMS2019 Aby użyć której z funkcji należy uprzednio wybrać urządzenie (wiersz).
- przycisk Link - testuje połączenie z wybranym urządzeniem
- przycisk Info – pobiera z urządzenia informacje i wyświetla je w oknie Info
- przycisk Delete – usuwa z arkusza wskazany wiersz
- przycisk Delete All – usuwa z arkusza wszystkie wiersze
- przycisk Arm – wysyła komendę „arm” do wybranego urządzenia
- przycisk Disarm - wysyła komendę „disarm” do wybranego urządzenia
- przycisk Reset - wysyła komendę „reset” do wybranego urządzenia
- przycisk Clear – czyści okno Info
- arkusz - zawiera informacje o urządzeniach, które logowały się do kontrolera Master:
- kolumna DEV# - numer wiersza
- kolumna GRP – adres Group urządzenia
- kolumna UNT – adres Unit urządzenia
- kolumna INFO – identyfikator urządzenia:
RES – master-reserve / PLY – player / PLY2 – player-reserve / KEY – keypad / STR – starter / SLV – moduł slave
- kolumna IDNO – numer seryjny urządzenia
4. Przycisk DEVICE – otwiera formatkę Device Setup
5. Formatka DEVICE SETUP – umożliwia obsługę serwisową urządzeń

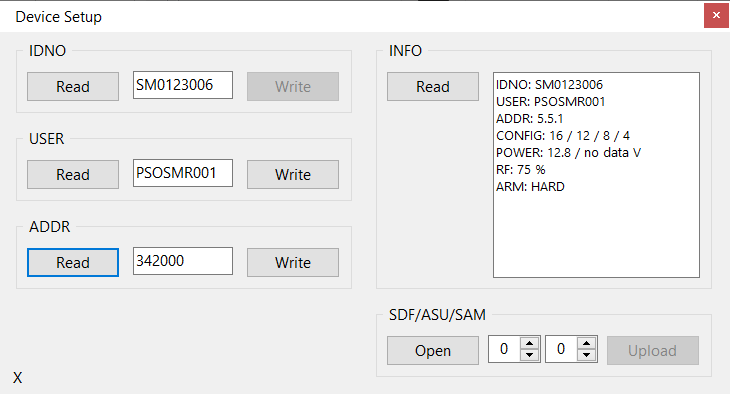
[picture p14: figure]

- grupa IDNO – umożliwia odczyt/zapis numeru seryjnego danego modułu, kliknij w pole edycji
- grupa USER - umożliwia odczyt/zapis oznaczenia danego modułu nadanego przez użytkownika
- grupa ADDR - umożliwia odczyt/zapis adresu slave danego modułu, kod do zapisu danych to „9876”
- grupa INFO - umożliwia odczyt informacji na temat danego modułu/urządzenia
- grupa SDF/ADU/SAM – umożliwia załadowanie skryptu SDF/ASU/SAM do wskzanego urządzenia
6. Przycisk Add – dodaje wskazne urządzenia do listy w Network Monitor
7. Przycisk MONITOR – otwiera formatkę Network Monitor
8. Formatka NETWORK MONITOR – pozwala nadzorować urządzenia pracujące w systemie
Aby użyć któreś z dostępnych funkcji należy uprzednio wybrać urządzenie (wiersz).
- przycisk Check All – pobiera dane z wszystkich urządzeń na liście
- przycisk Check – pobiera dane ze wskazanego urządzenia
- przycisk Delete All – usuwa z listy wszystkie urządzenia
- przycisk Delete – usuwa z listy wskazane urządzenie
- arkusz Devices - zawiera informacje o monitorowanych urządzeniach:
- kolumna DEV# - numer wiersza
- kolumna GRP – adres Group urządzenia
- kolumna UNT – adres Unit urządzenia
- kolumna INFO – identyfikator urządzenia:
RES – master-reserve / PLY – player / PLY2 – player-reserve / KEY – keypad / STR – starter / SLV – moduł slave
Datasheet: pyrobox-guide-pbm711412-summary-pl.pdf | Page: 5 / 18

- kolumna IDNO – fabryczny numer seryjny urządzenia
- kolumna USER – oznaczenie urządzenia nadane mu przez użytkownika
- kolumna CFG – konfiguracja wyjść urządzenia według klucza:
moduł#1 / moduł#2 / moduł#3 / moduł#4
liczba oznacza liczbę sekcji w module,
0 oznacza że moduł nie jest obsługiwany przez slave
- kolumna B1 – napięcie akumulatora nr 1 (wewnętrznego)
- kolumna B2 - napięcie akumulatora nr 2 (zewnętrznego)
- kolumna RF – poziom sygnału radiowego w %
- kolumna ARM – urządzenie:
SAFE – bezpieczne
H+ - kluczyk w pozycji ARM
S+ - uzbrojone przez Master
ARM – w pełni uzbrojone
- kolumna LT – informacja o wyniku Link Test: OK / ERR

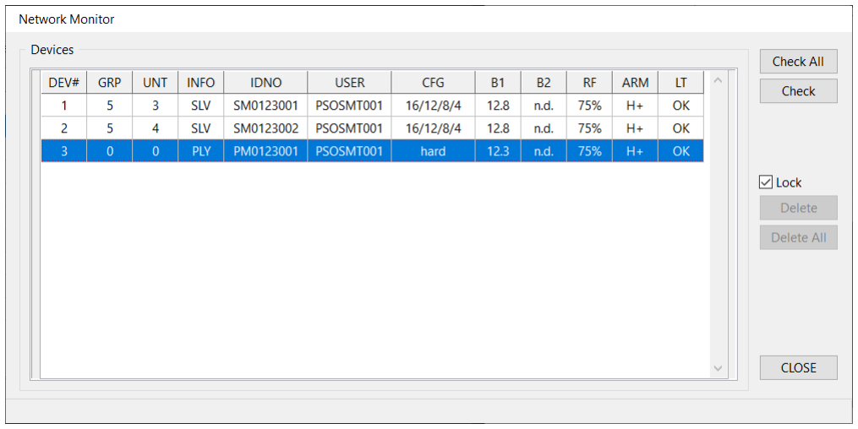
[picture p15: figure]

9. Przycisk OUM (One Unit Monitor) – otwiera formatki MONITOR dla wybranych urządzeń
10. Formatka MONITOR – pozwala nadzorować dowolne urządzenie pracujące w systemie

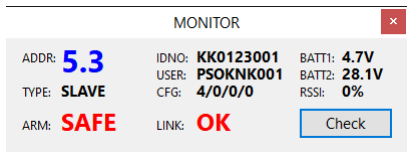
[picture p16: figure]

- przycisk Check – pobiera dane z monitorowanego urządzenia

### A3. Formatka TESTER

1. Grupa Setup – służy do wskazania urządzenia do testów
- przycisk Slave – nawiązuje połączenie z urządzeniem, adres jak w polach wyboru (group+unit), i pobiera informacje o jego konfiguracji np. liczbie sekcji
- grupa Mode – ustawia tryb pracy testera: Module, Section lub Channel
2. Grupa Address > G.U/M.S.C – umożliwia ustawienie adresu testowanego modułu/sekcji/kanału
3. Przycisk TEST – uruchamia procedurę testowania
4. Grupa Result > G.U/M – prezentuje wyniki testów
- wskaźnik informuje o postępie procedury testowania
- Grupa Section / Channel – prezentuje wyniki testów
Datasheet: pyrobox-guide-pbm711412-summary-pl.pdf | Page: 6 / 18

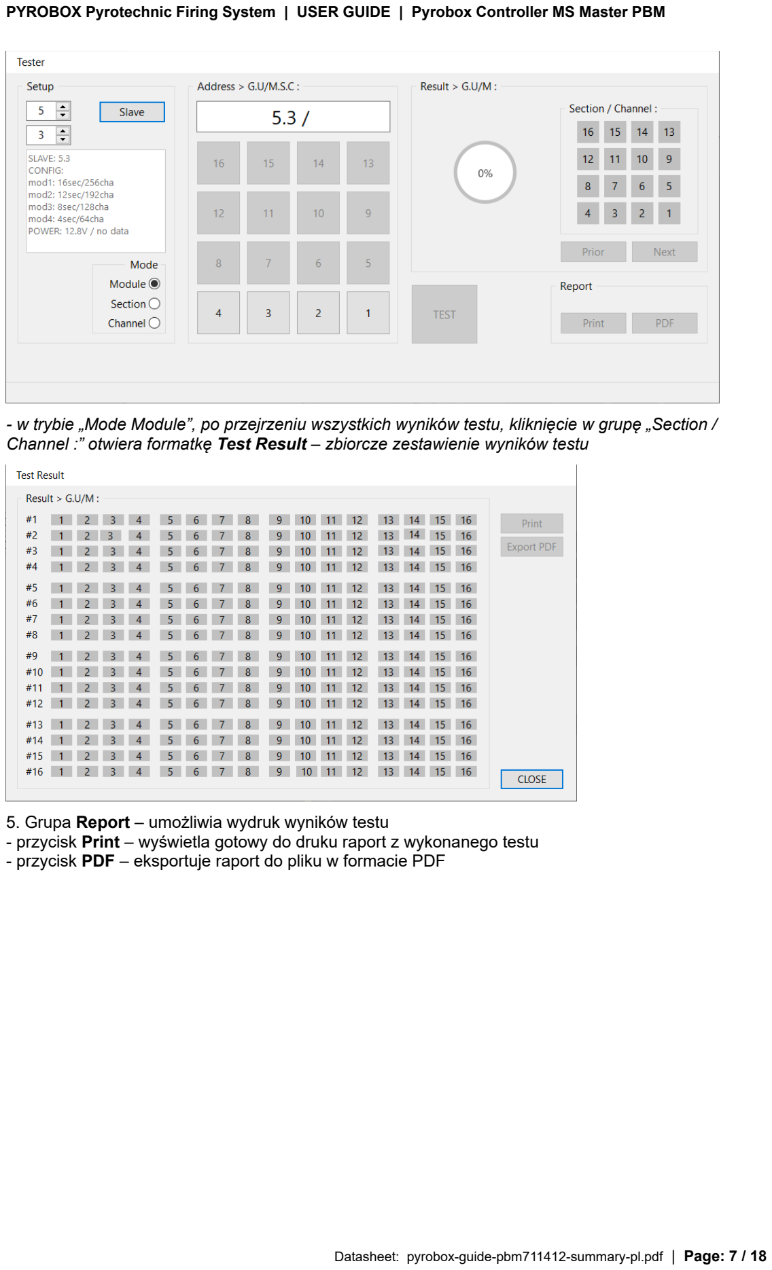
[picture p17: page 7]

- w trybie „Mode Module”, po przejrzeniu wszystkich wyników testu, kliknięcie w grupę „Section / Channel :” otwiera formatkę Test Result – zbiorcze zestawienie wyników testu
5. Grupa Report – umożliwia wydruk wyników testu
- przycisk Print – wyświetla gotowy do druku raport z wykonanego testu
- przycisk PDF – eksportuje raport do pliku w formacie PDF
Datasheet: pyrobox-guide-pbm711412-summary-pl.pdf | Page: 7 / 18

## B. AUTO CONTROL

### B1. Formatka EDITOR

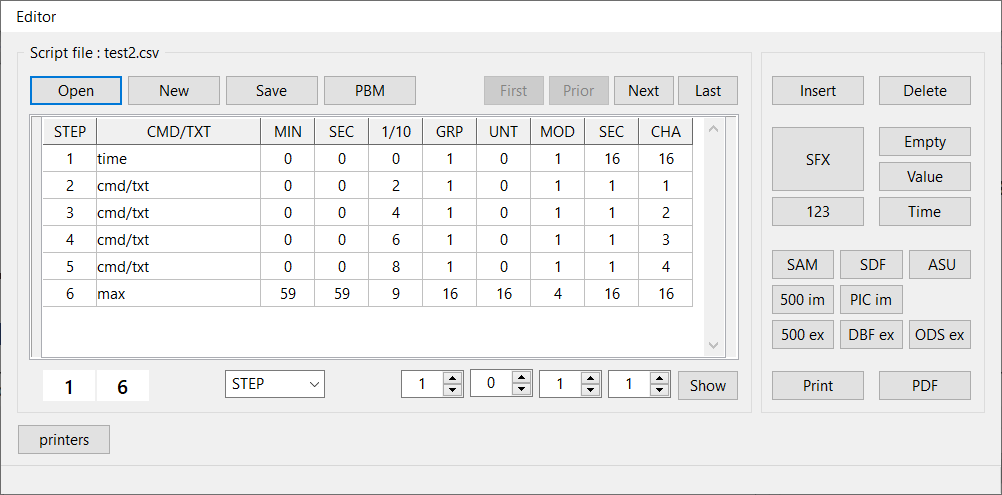
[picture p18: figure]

1. Grupa Script file – służy do tworzenia i edycji skryptów
- przycisk Open – otwiera skrypt do edycji
- przycisk New – otwiera nowy skrypt do edycji
- przycisk Save – zapisuje skrypt pod wskazaną nazwą
- przycisk PBM – zapisuje skrypt w formacie [.pbm], otwiera formatkę Stepper oraz okno Open script
- przyciski First/Prior/Next/Last – umożliwiają poruszanie się po arkuszu
- przycisk Show + pola wyboru – umożliwiają sortowanie zapisów skryptu i podgląd tych wybranych
2. elementy skryptu
- kolumna STEP – numer wiersza w skrypcie
- kolumna CMD/TXT – komenda lub komentarz
- kolumna MIN – czas wykonania komendy → minuta
- kolumna SEC – czas wykonania komendy → sekunda
- kolumna 1/10 – czas wykonania komendy → dziesiętna cześć sekundy
- kolumna GRP – adres obwodu zapalczego → grupa, zakres 1..16
- kolumna UNT – adres obwodu zapalczego → jednostka, zakres 1..16, 0 oznacza wszystkie jednostki
- kolumna MOD – adres obwodu zapalczego → moduł, zakres 1..4
- kolumna SEC – adres obwodu zapalczego → sekcja, zakres 1..16
- kolumna CHA – adres obwodu zapalczego → kanał, zakres 1..16
3. narzędzia do edycji skryptu
- przycisk Insert – wstawia do arkusza nowy wiersz
- przycisk Delete – usuwa z arkusza wskazany wiersz
- przycisk SFX – otwiera/zamyka formatkę Special Functions
- przycisk 123 – renumeruje kolejno wiersze
- przycisk Empty – wyszukuje puste komórki w skrypcie
- przycisk Value - wyszukuje niedopuszczalne wartości w skrypcie
- przycisk Time - sprawdza odstępy czasu pomiędzy wierszami
- przycisk SAM – otwiera formatkę SAM Script Generator, (SAM - Script for Autonomic Mode)
- przycisk SDF – zapisuje skrypt SDF, format [.sft]
- przycisk ASU - zapisuje skrypt ASU, format [.sfa]
- przycisk 500 im – importuje skrypt z programu Pyrobox Controller MS w wersji 500
- przycisk PIC im – importuje skrypt z programu PyroIgnitionControl
- przycisk 500 ex – exportuje skrypt do programu Pyrobox Controller MS w wersji 500
- przycisk DBF ex – exportuje skrypt do programu Pyrobox Controller PBC, format [.dbf]
- przycisk ODS ex – exportuje skrypt do arkusza kalkulacyjnego, format [.ods]
- przycisk Print – wyświetla raport do druku, można go ewentualnie zapisać
- przycisk PDF – zapisuje i wyświetla raport w formacie PDF
4. Przycisk printers - otwiera systemowe okno „Ustawienia wydruku”
Datasheet: pyrobox-guide-pbm711412-summary-pl.pdf | Page: 8 / 18

5. Formatka SPECIAL FUNCTIONS – ułatwia zapis w skrypcie komend funkcji specjalnych

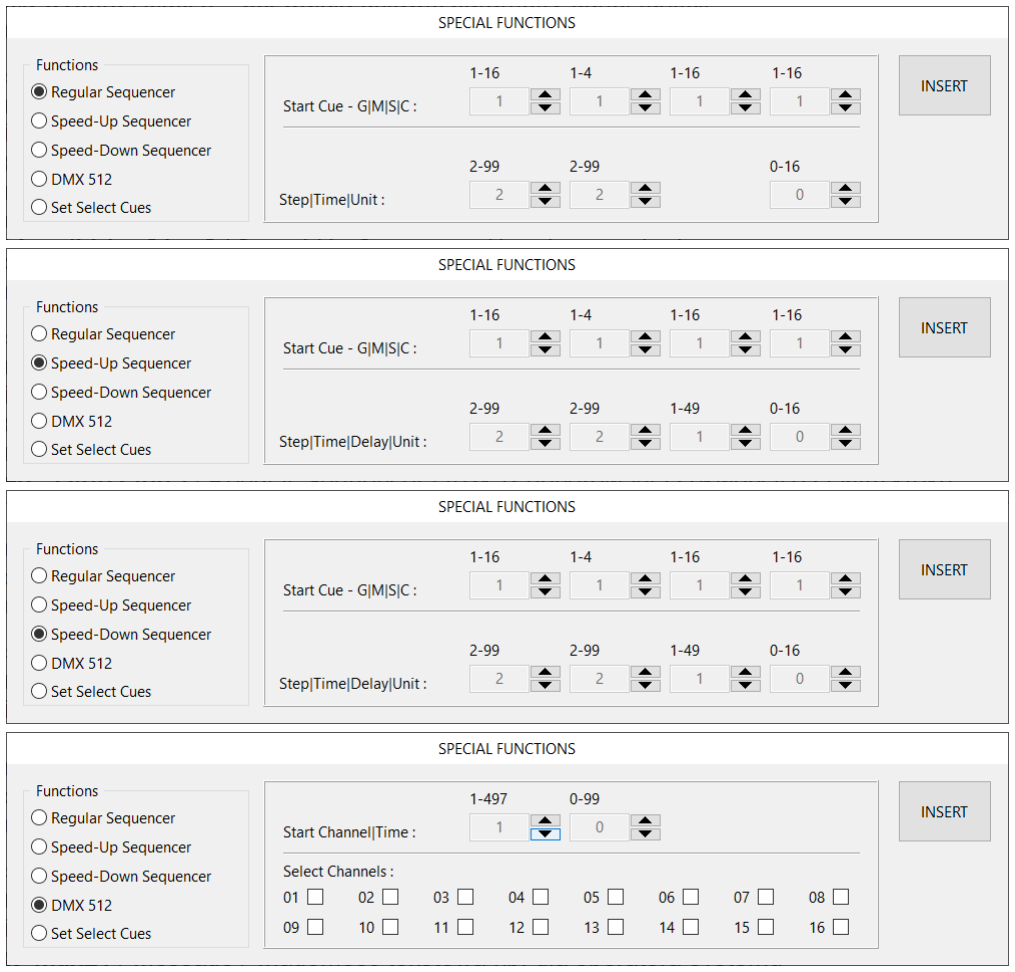
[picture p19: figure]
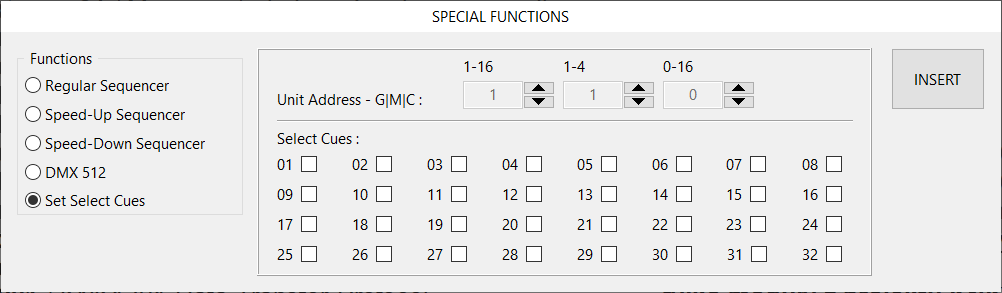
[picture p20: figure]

- grupa Functions – zawiera klucze wyboru funkcji do edycji
- pola wyboru i klucze – pozwalają ustawić parametry danej funkcji
- przycisk INSERT – wstawia gotową komendę do wiersza skryptu Dostępne w programie funkcje specjalne:
- time / Starter / rozkaz startu dla wszystkich urządzeń w sieci systemu
- ping / Heartbeat / generowanie pojedyńczego sygnału „heartbeat”
- txt=max21 / Message / wiadomośc tekstowa np. dla operatora systemu
- imp=xxx [ /nn ] / Fire-Pulse-Corrector / generowanie impulsu „fire” o zadanym czasie
- seq=aa/bb [ /nn ] / Regular-Sequencer / rozkaz generowania sekwencji o stałym kroku
- shi=aa/bb/cc [ /nn ] / Speed-Up-Sequencer / jw. skracany krok
- slo=aa/bb/cc [ /nn ] / Speed-Down-Sequencer / jw. wydłużany krok
Datasheet: pyrobox-guide-pbm711412-summary-pl.pdf | Page: 9 / 18

- sdf=xxx [ /nn] / Programming-Sequencer / jw. zaprogramowany krok | → skrypty SDF
- all=xxx / All-Slave-Units / rozkaz wykonania zaprogramowanych zadań | → skrypty ASU
- one=nn / One-In-Group / oznacza że rozkaz z danego wiersza dotyczy tylko wskazanej jednostki
- nxt=x / Zero-Delay-Firing / rozkaz jednoczesnego wykonania komend z „x” kolejnych wierszy
- set=xxxxxxxx [ /nn] / Set-Select-Cues | → tylko dedykowane moduły
- 1301 / KNK1301-Data-Transfer-Protocol | → tylko moduły z projektu KNK1301
oraz te obsługujące urządzenia DMX:
- dmx=xxx/yyyy/zz / DMX512-Switch / rozkaz - ustaw kanały od „xxx” wg klucza „yyyy” na czas „zz”
- dx1=xxx/yyy / DMX512-Value / ustaw kanał „xxx” na wartość „yyy”
- dx2=xxx/yyy/zzz/nn / DMX512-PWM / zmień ustawienie kanału „xxx” z „yyy” na „zzz” w czasie „nn”
- dx3=xxx/yyy/zzz/nnn/mmm / DMX512-Value-4 / ustaw wartości 4 kolejnych kanałów od „xxx”
- ewe=xxx/yy / EXPLO-Wave-Flamer-Easy-DMX | → NOT YET READY
- ewf=xxx/yy / EXPLO-Wave-Flamer-DMX512 | → NOT YET READY
Uwaga! „0” w kolumnie UNT oznacza, że zapisy wiersza dotyczą wszystkich jednostek w grupie. Inne wartości odnoszą się do konkretnych jednostek, co jest równoznaczne z zapisem [ /nn ].
5. Formatka SAM SCRIPT GENERATOR – umożliwia przygotowanie skryptów SAM
- pole Show – pozwala nadać prefix skryptom danego widowiska, nazwa skryptu jest widoczna niżej
- klucz Select – włącza sortowanie po adresach urządzeń group+unit
- przycisk RUN – uruchamia sortowanie danych dla wskazanego urządzenia
- przycisk SAVE - zapisuje pod wskazaną nazwą wybrane dane jako skrypt SAM, format [.sam]

### B2. Formatka PLAYER

1. Grupa Audio file – obsługuje pliki audio WAV (prferowane) oraz MP3
- przycisk Open – otwiera plik audio w formacie [.wav] lub [.mp3]
- przyciski Play/Pause/Stop – sterują pracą Playera
- suwaki L/R - regulują poziom głośności dźwięku
- przycisk Mute – w ciągu 3 sekund wycisza stopniowo dźwięk

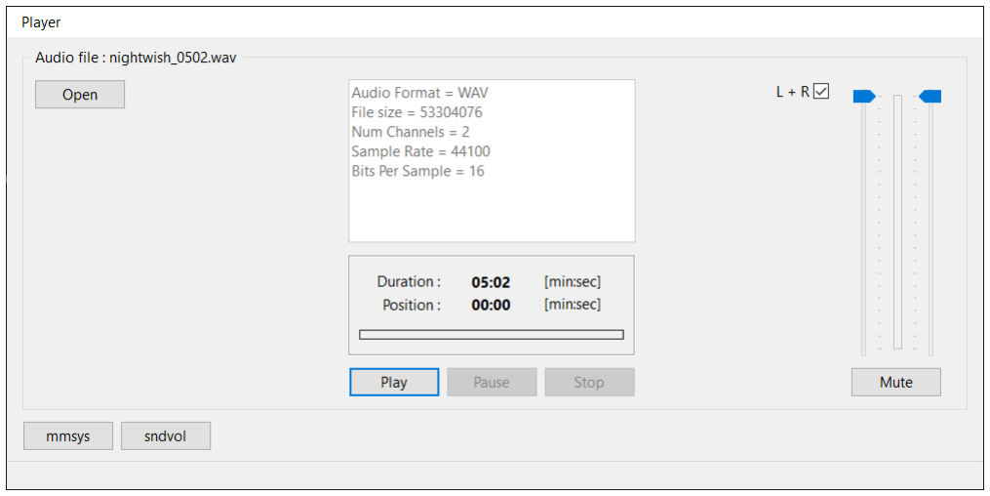
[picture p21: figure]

2. Przycisk mmsys – otwiera systemowe okno „Dźwięk”
3. Przycisk sndvol - otwiera systemowe okno „Mikser głośności”
Datasheet: pyrobox-guide-pbm711412-summary-pl.pdf | Page: 10 / 18

### B3. Formatka STEPPER

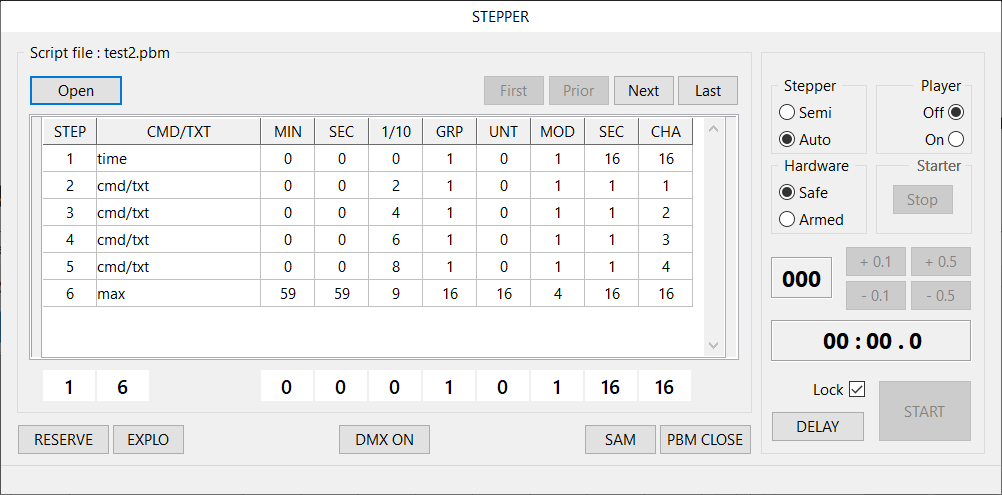
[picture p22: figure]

1. Grupa Script file - – służy do obsługi skryptów
- przycisk Open – otwiera skrypt roboczy
- przyciski First/Prior/Next/Last – umożliwiają poruszanie się po skrypcie
2. Grupa Stepper – ustawia tryb pracy Steppera: Semi lub Auto
3. Grupa Player – dołącza/odłącza Playera od Steppera
4. Grupa Hardware – uzbraja/rozbraja urządzenia w systemie
5. Grupa Starter – przycisk Stop awaryjnie blokuje działanie NET/DMX Startera
6. Przyciski +0.1 / +0.5 / -0.1 / -0.5 – umożliwiają korygowanie odliczanego czasu
7. Przycisk DELAY – otwiera/zamyka formatkę Delay
8. Przycisk START – uruchamia Stepper
9. Przycisk RESERVE – otwiera/zamyka formatkę Reserve
10. Przycisk EXPLO – otwiera/zamyka formatkę Explo
11. Przycisk DMX ON (OFF) – otwiera/zamyka transmisję danych poprzez port DMX
12. Przycisk SAM – otwiera/zamyka formatkę SAM setup
13. Przycisk PBM CLOSE (OPEN ) – wysyła komendę „switch” i zamyka/otwiera port PBM
14. Formatka DELAY – umożliwia ustawienie zwłoki startu
- pola wyboru [SEC] oraz [1/10] – służą do ustawienia czasu zwłoki
- klucz Remote - włącza tryb oczekiwania na sygnał startu z zewnątrz np. ze startera
- przycisk START – uruchamia Stepper

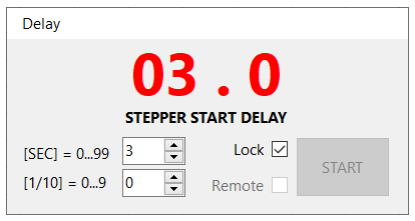
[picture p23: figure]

15. Formatka RESERVE – służy do konfikuracji i odpalania zapasowych obwodów zapalczych
- grupy Preset 1 / Preset 2 / Preset 3 / Preset 4 – zapasowe obwody
- przyciski Fire 1 / Fire 2 / Fire 3 / Fire 4 – odpalają zaprogramowane obwody zapalcze

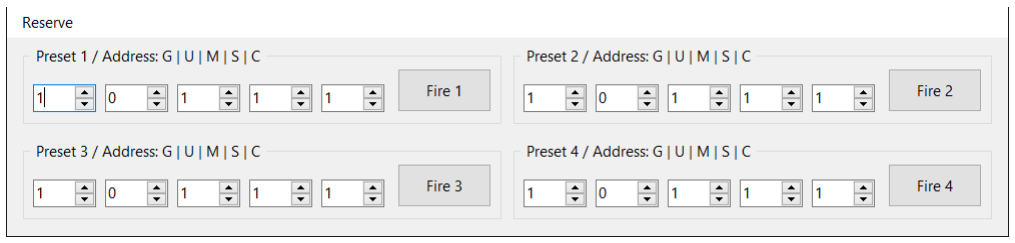
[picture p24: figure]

Datasheet: pyrobox-guide-pbm711412-summary-pl.pdf | Page: 11 / 18

16. Formatka EXPLO X2 WAVE FLAMER Setup – służy do uzbrajania/rozbrajania urządzeń Explo
- pola wyboru – pozwalają ustawić adresy stratowe DMX urządzeń Explo X2 Wave Flamers
- przyciski ON (zmiana na ARMED|OFF) – zdejmują zabezpieczenie z danego urządzenia
- przyciski OFF (zmiana na ON|SAFE) – zakładają zabezpieczenie na dane urządzenie
- przycisk 1..8 ON – zdejmuje zabezpieczenia z wszystkich urządzeń
- przycisk 1..8 OFF – zakłada zabezpieczenia na wszystkie urządzenia
Uwaga! Ta wersja programu nie obsługuje jeszcze urządzeń firmy Explo.
17. Formatka SAM SETUP – służy do włączania/wyłączania trybu SAM (Slave Autonomic Mode)
- przycisk NTP – uruchamia synchronizację czasu systemowego komputera z serwerem NTP
- przycisk ON/OFF – włącza/wyłącza tryb SAM
Datasheet: pyrobox-guide-pbm711412-summary-pl.pdf | Page: 12 / 18

## C. MANUAL CONTROL

### C1. Formatka PBM

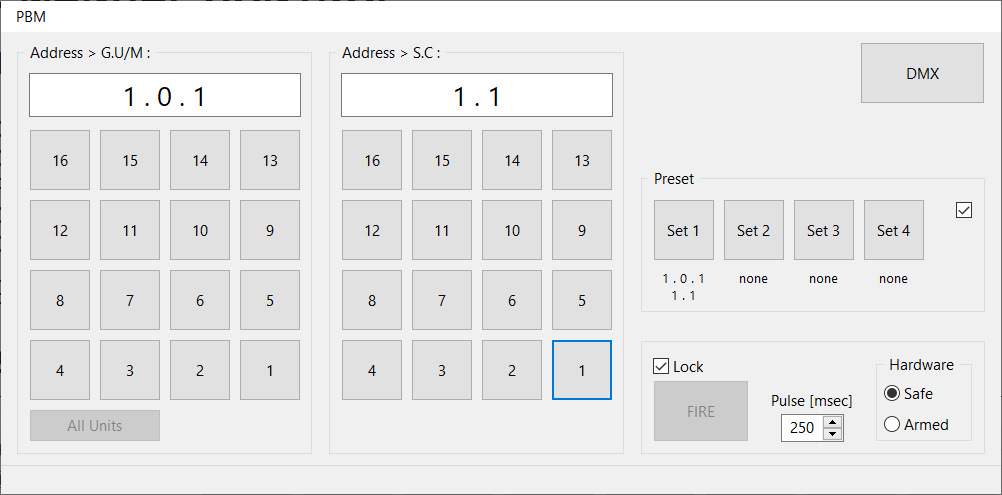
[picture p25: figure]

1. Grupa Address > G.U/M – umożliwia ustawienie adresu group/unit/module obwodu zapalczego
2. Grupa Address > S.C – umożliwia ustawienie adresu section/channel
3. Przycisk DMX – przełącza na formatkę DMX
4. Grupa Preset – cztery programowalne przyciski
- klucz zmienia tryb pracy tych przycisków z trybu programowania w tryb odpalania
5. Grupa Hardware – uzbraja/rozbraja moduły (urządzenia) w sieci systemu
6. Lista wyboru Pulse – ustawia żądany czas impulsu odpalającego [msec]
7. Przycisk FIRE – odpala wybrany obwód zapalczy

### C2. Formatka PBM STAGE

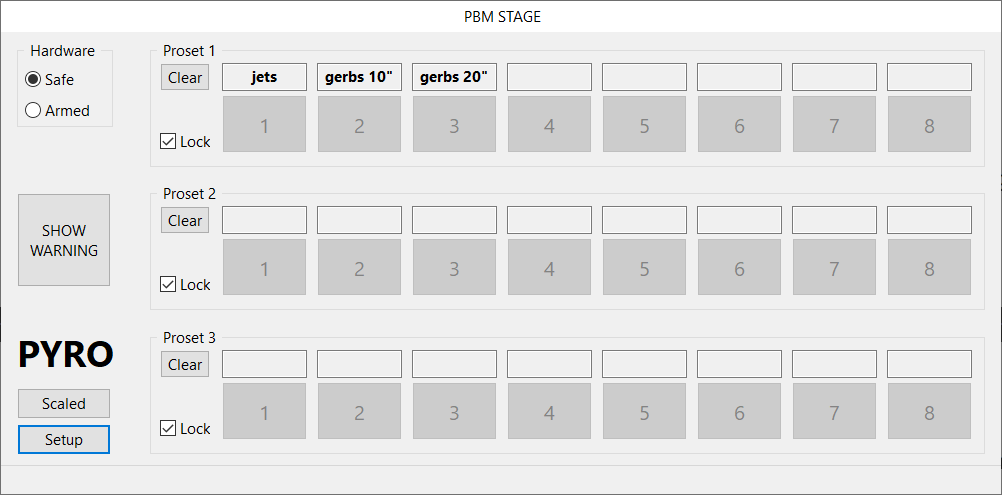
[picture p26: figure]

1. Grupa Proset 1 / Proset 2 / Proset 3 – grupy przycisków do zaprogramowania
- pola edycji – służą do opisywania przycisków
- przyciski Clear – czyszczą pola edycji
- klucze Lock – blokują/odblokowują przyciski
2. Grupa Hardware – uzbraja/rozbraja urządzenia w systemie
3. Przycisk SHOW(HIDE) WARNING – włącza/wyłącza sygnalizację gotowości urządzeń do pracy
4. Przycisk Scaled – przeskalowuje formatkę
5. Przycisk Setup – otwiera formatkę PBM Stage Setup
Datasheet: pyrobox-guide-pbm711412-summary-pl.pdf | Page: 13 / 18

6. Formatka PBM STAGE SETUP – służy do programowania przycisków na PBM Stage
- przycisk Open – otwiera plik ustawień
- przycisk New – tworzy nowy plik ustawień
- przycisk Save – zapisuje otwarty plik ustawień
- przycisk Clear – przywraca komórkom domyślne wartości

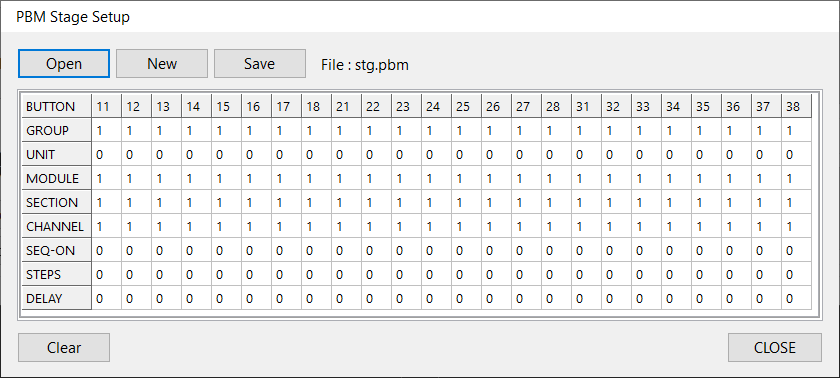
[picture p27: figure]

- komórka GROUP – adres grupy obwodu przypisanego do danego przycisku, zakres 1..16
- komórka UNIT – adres jednostki, zakres 1..16, 0 oznacza wszystkie jednostki w grupie
- komórka MODULE – adres modułu, zakres 1..4
- komórka SECTION – adres sekcji, zakres 1..16
- komórka CHANNEL – adres kanału, zakres 1..16
- komórka SEQ ON – klucz włączający sekwencer (0/1)
- komórka STEPS – liczba kroków w sekwencji, zakres ograniczony do obrębu sekcji
- komórki DELAY – czas opóźnienia pomiędzy krokami x 0.1 sec, zakres 2..50

### C3. Formatka DMX

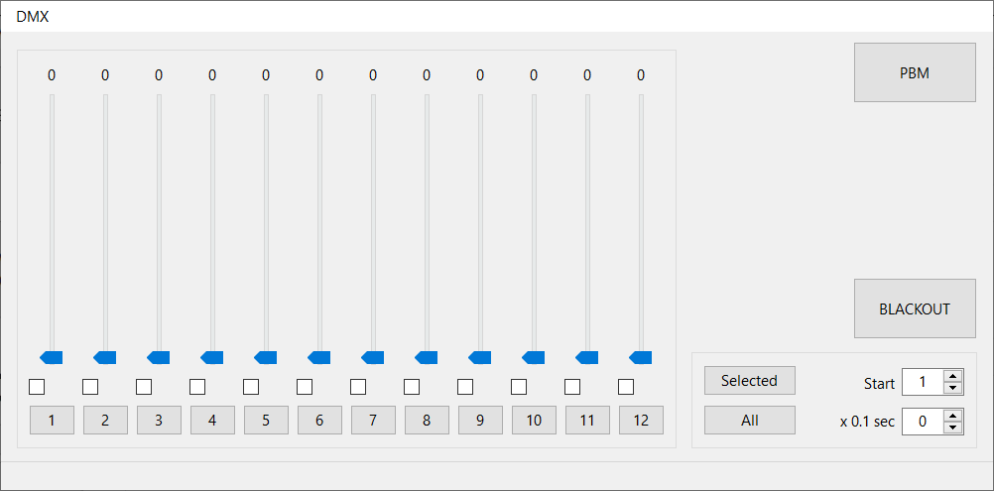
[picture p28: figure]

1. Suwaki 1..12 – pozwalają ustawić żądaną wartość na danym kanale DMX
2. Klucze 1..12 – dołączają dany kanał do przycisku Selected
3. Przyciski 1..12 – włączają/wyłączają dany kanał
4. Przycisk Selected – załącza/wyłącza wybrane kanały
5. Przycisk All – załącza/wyłącza wszystkie kanały
6. Lista wyboru Start address – ustawia adres startowy dla obsługiwanych kanałów DMX
7. Lista wyboru Delay – ustawia czas załączenia wybranego lub wszystkich kanałów
8. Przycisk BLACKOUT – zeruje wszystkie kanały DMX
9. Przycisk PBM – przełącza na formatkę PBM
Datasheet: pyrobox-guide-pbm711412-summary-pl.pdf | Page: 14 / 18

### C4. Formatka DMX STAGE

1. Grupa Proset 1 / Proset 2 / Proset 3 – grupy przycisków do zaprogramowania
- pola edycji – służą do opisywania przycisków
- przyciski Clear – czyszczą pola edycji
- klucze Lock – blokują/odblokowują przyciski
2. Przycisk BLACKOUT – zeruje wszystkie kanały DMX
3. Przycisk WARNING ON/OFF – włącza/wyłącza sygnalizację gotowości urządzeń do pracy
4. Przycisk Scaled – przeskalowuje formatkę
5. Przycisk Setup – otwiera formatkę Setup (DMX Stage)

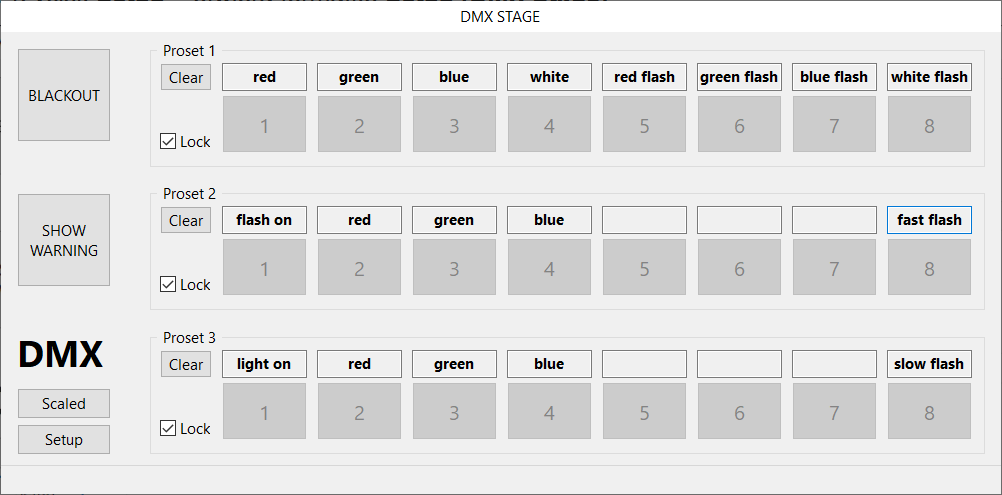
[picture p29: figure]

5. Formatka DMX STAGE SETUP – służy do programowania przycisków DMX Stage
- przycisk Open – otwiera plik ustawień
- przycisk New – tworzy nowy plik ustawień
- przycisk Save – zapisuje otwarty plik ustawień
- przycisk Clear – przywraca komórkom domyślne wartości

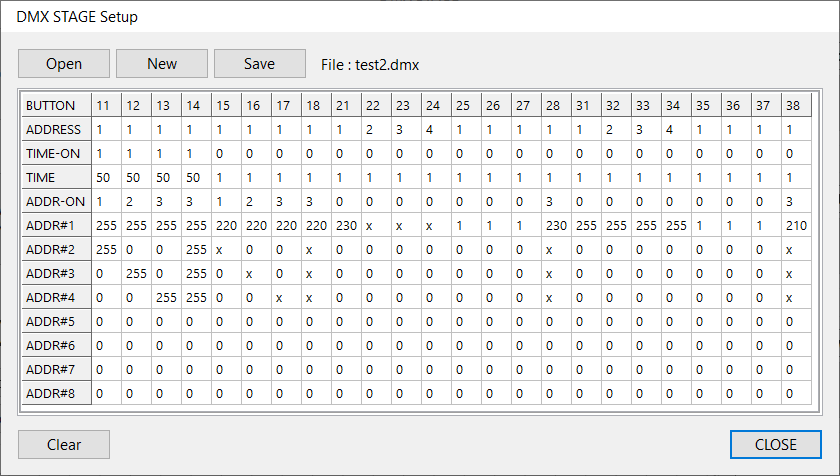
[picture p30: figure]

- komórka ADDRESS – adres kanału DMX przypisany do danego przycisku
- komórka TIME ON – klucz włączający timer (0/1)
- komórka TIME – czas odliczany przez timer x 0.1 sec, zakres 1..99
- komórka ADDR ON – klucz 0..7 dołączający kolejne kanały ADDR #2..8
- komórki ADDR #1..8 – klucze ustawiające wartości kanałów (0=0/val=0..255/x=255)
Datasheet: pyrobox-guide-pbm711412-summary-pl.pdf | Page: 15 / 18

## D. FIRST STEPS

### D1. Instalacja i konfiguracja programu

Instalacja programu:
- program można pobrać ze strony https://www.pyrobox.com.pl/soft/downloads.html
- instalacja programu przebiega w sposób typowy dla systemu Windows
- po instalacji katalogi robocze programu mają następującą strukturę:
C:\Program files (x86)\pbm700\
[csv] | - katalog skryptów w formacie [.csv] przeznaczonych dla Edytora
[dbf] | - katalog skryptów w formatach [.dbf] oraz [.mdx] przeznaczonych dla Pyrobox PBC
[exe] | - katalog raportów z edytowanych skryptów w formatach [.lrf] oraz [.pdf]
[pbm] | - katalog skryptów w formacie [.pbm] przeznaczonych dla Steppera
[reg] | - katalog plików tymczasowych programu
[sam] | - katalog skryptów w formacie [.sam] przeznaczonych dla urządzeń slave z funkcją SAM
[stg] | - katalog plików setup w formatach [.pbm] dla PBM Stage oraz [.dmx] dla DMX Stage
[wav] | - katalog plików audio w formatach [.wav] oraz [.mp3]
unins000.dat
bass.dll
ftd2xx.dll
pbm.exe
unins000.exe
C:\Users\ (user name) \AppData\Roaming\pyrobox\pbm700\
[exe] | - katalog plików konfiguracyjnych programu w formatach [.csv] oraz [.ini]
[reg] | - katalog raportów MRX/MTX/REG z pracy programu w formacie [.txt]
Wymiana danych pomiędzy urządzeniami w systemie odbywa się za pośrednictwem magistrali RS485, aby więc przyłączyć komputer do sieci systemu konieczny jest konwerter USB/RS485. Stosowane konwertery instalowane są w Windows jako wirtualne porty VCP (Virtual COM Port). VCP (Virtual COM Port) drivers (https://ftdichip.com/drivers/vcp-drivers/)
System może również współpracować z urządzeniami DMX wykorzystując konwerter USB/DMX512. W zależności od trybu transmisji danych (jedno lub dwukierunkowa) stosowane są odpowiednio konwertery Enttec OPEN DMX USB (także tanie klony) lub Enttec DMX USB PRO.
Enttec OPEN DMX USB (https://www.enttec.co.uk/en/product/lighting-communication-protocols/dmx512/open-dmx-usb/)
Enttec DMX USB PRO (https://www.enttec.co.uk/en/product/controls/dmx-usb-interfaces/dmx-usb-pro/)
Konfiguracja programu:
- podłącz do komputera konwerter USB/RS485, zaczekaj na zakończenie instalcji sterowników,
a następnie odłącz go od komputera
- jeżeli chcesz korzystać z urządzeń DMX to podobnie postąp z konwerterem USB/DMX512
- uruchom program (prawdopodobnie uruchomi się z komunikatem Windows, że wydawca programu jest nieznany, dzieje się tak ponieważ nie został on podpisany cyfrowo i zarejestrowany w płatnej bazie Windows), otwórz formatkę Setup
- podłącz konwerter USB/RS485, wybierz podpowiedziany port COM, otwórz port
- zrób to samo z konwerterem USB/DMX512, jeśli chcesz z niego korzystać
- zamknij i uruchom ponownie program, konwertery zostaną przyłączone automatycznie
- ustaw odpowiednie tryby pracy Mode/Stepper/Player

### D2. Przygotowania i realizacja widowiska

Edycja skryptu roboczego:
- przejdź do formatki Editor, utwórz i wyedytuj nowy skrypt widowiska
- w pierwszym wierszu o czasie 0:0.0 wpisz funkcję „time”
- poprawność skryptu możesz zweryfikowac przy pomocy funkcji Empty/Value/Time
- możesz go także wydrukować i porównać ze scenariuszem widowiska
- zweryfikowany skrypt zapisz przy pomocy funkcji PBM w formacie właściwym dla Steppera
- przejdź do formatki Setup i wprowadź PIN aby uzyskać dostęp do wszystkich funkcji programu
- przejdź do formatki Stepper, otwórz utworzony skrypt
- możesz teraz wypróbować skrypt, odblokuj i naciśnij przycisk START
Datasheet: pyrobox-guide-pbm711412-summary-pl.pdf | Page: 16 / 18

Realizacja widowiska:
- po podpięciu do magistrali systemu wszystkich urządzeń wykorzystywanych w widowisku (rysunek na następnej stronie), możesz (korzystając z formatki Network) sprawdzić połączenia w sieci, oraz (używając formatki Tester) przetestować obwody zapalcze
- jeśli wszystko jest w porządku możesz przystąpić do realizacji widowiska
- przejdź do formatki Setup i wprowadź PIN aby uzyskać dostęp do wszystkich funkcji programu
- przejdź do formatki Stepper i otwórz skrypt widowiska
- uzbrój wszystkie urządzenia - przełącz kluczyki na pozycje Armed
- bezpośrednio przed widowiskiem uzbrój system - zaznacz klucz Hardware/Armed
- odblokuj i naciśnij przycisk START
- po zakończeniu widowiska rozbrój system - zaznacz klucz Hardware/Safe
- rozbrój wszystkie urządzenia - przełącz kluczyki na pozycje Safe

### D3. Podpowiedzi i pomoce

W trakcie realizacji widowiska program może jednocześnie odtwarzać jego podkład muzyczny, jednak w wielu przypadkach wygoniej będzie skorzystać ze zdalnego odtwarzacza muzyki.
Taką funkcje może pełnić komputer z zainstalowanym programem Pyrobox Player PBP, który można pobrać ze strony https://www.pyrobox.com.pl/soft/downloads.html
Na wskazanej stronie dostępnych jest również kilka starterów, które pozwalają zsynchronizować pracę systemu z innymi multimediami.

Pomocne materiały:

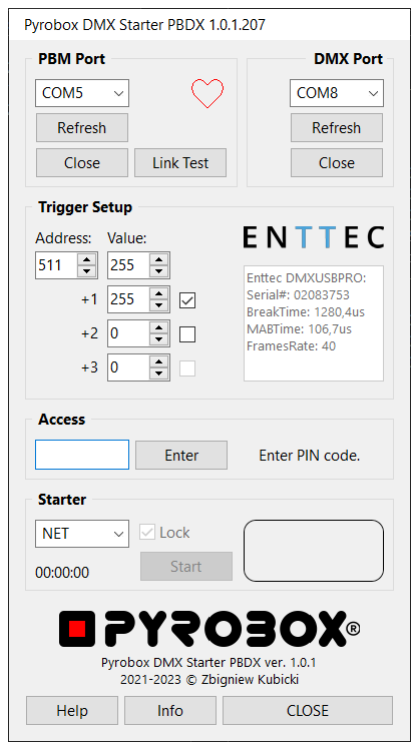
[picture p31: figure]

https://www.pyrobox.com.pl/pdf/pyrobox-cfg-pl.pdfhttps://www.pyrobox.com.pl/pdf/pyrobox-addr-pl.pdfhttps://www.pyrobox.com.pl/pdf/pbms2019-protocol-2.0-pl.pdfhttps:/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
i więcej na stronie https://www.pyrobox.com.pl/hard/downloads.html

### UWAGA!

Aktualnie nie jest dostępna kompletna instrukcja obsługi programu Pyrobox Controller MS Master PBM w wersji 7.1.0 dlatego też proszę posiłkować się instrukcją dla Pyrobox Controller MS 5.0.0 https://www.pyrobox.com.pl/pdf/pl-pbm500-101.pdf
Komplet informacji na temat systemu Pyrobox znajduje się na stronie https://pyrobox.com.pl
Datasheet: pyrobox-guide-pbm711412-summary-pl.pdf | Page: 17 / 18

### D4. System rozległy Pyrobox

Poniższy rysunek prezentuje ogólne zasady budowy sieci systemu Pyrobox oraz różne możliwości jej konfiguracji w oparciu o aktualnie dostępne elementy systemu.

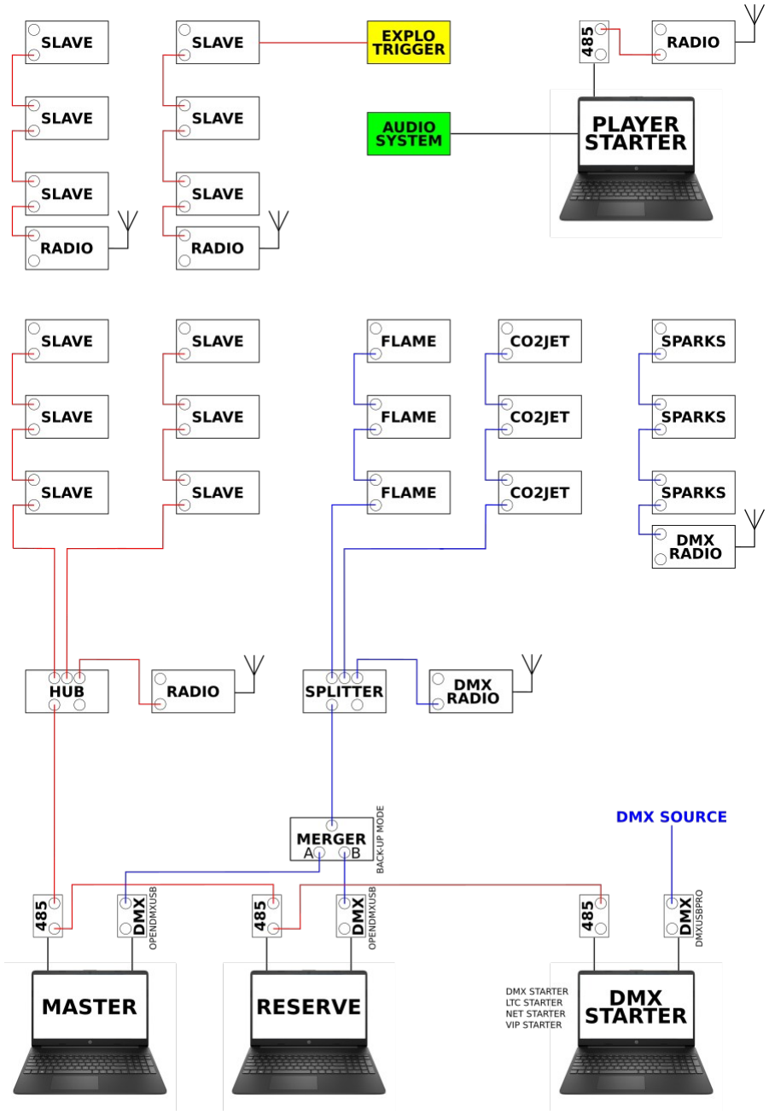
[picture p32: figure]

Datasheet: pyrobox-guide-pbm711412-summary-pl.pdf | Page: 18 / 18

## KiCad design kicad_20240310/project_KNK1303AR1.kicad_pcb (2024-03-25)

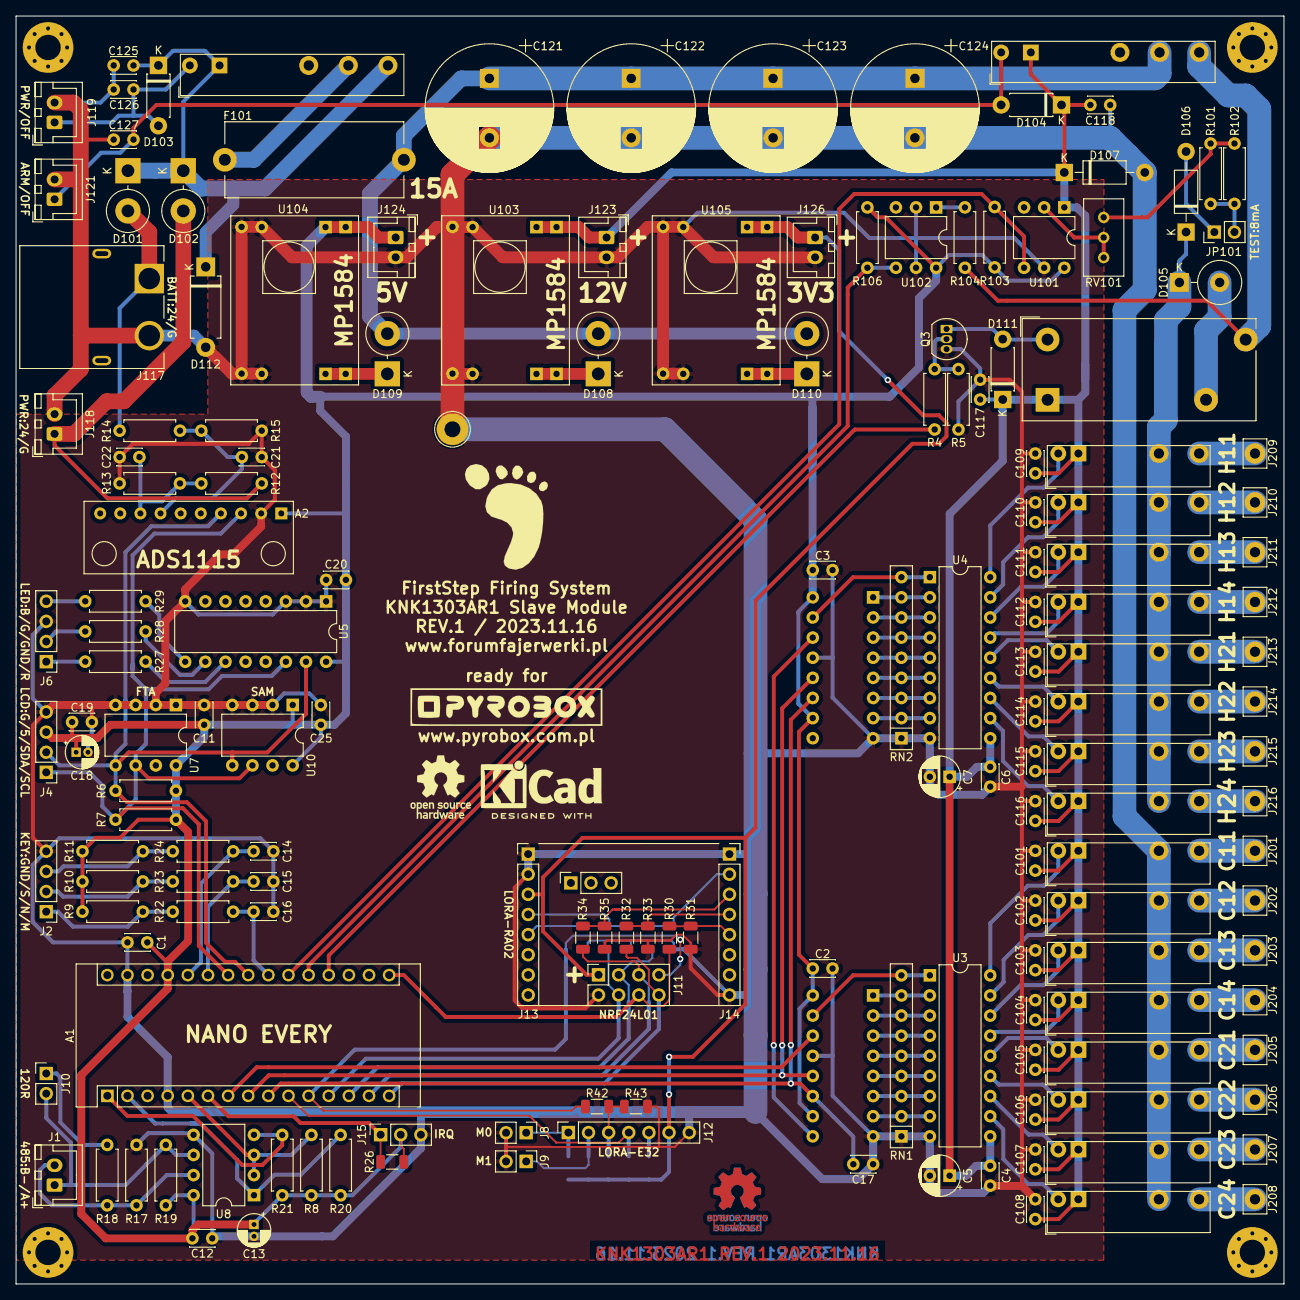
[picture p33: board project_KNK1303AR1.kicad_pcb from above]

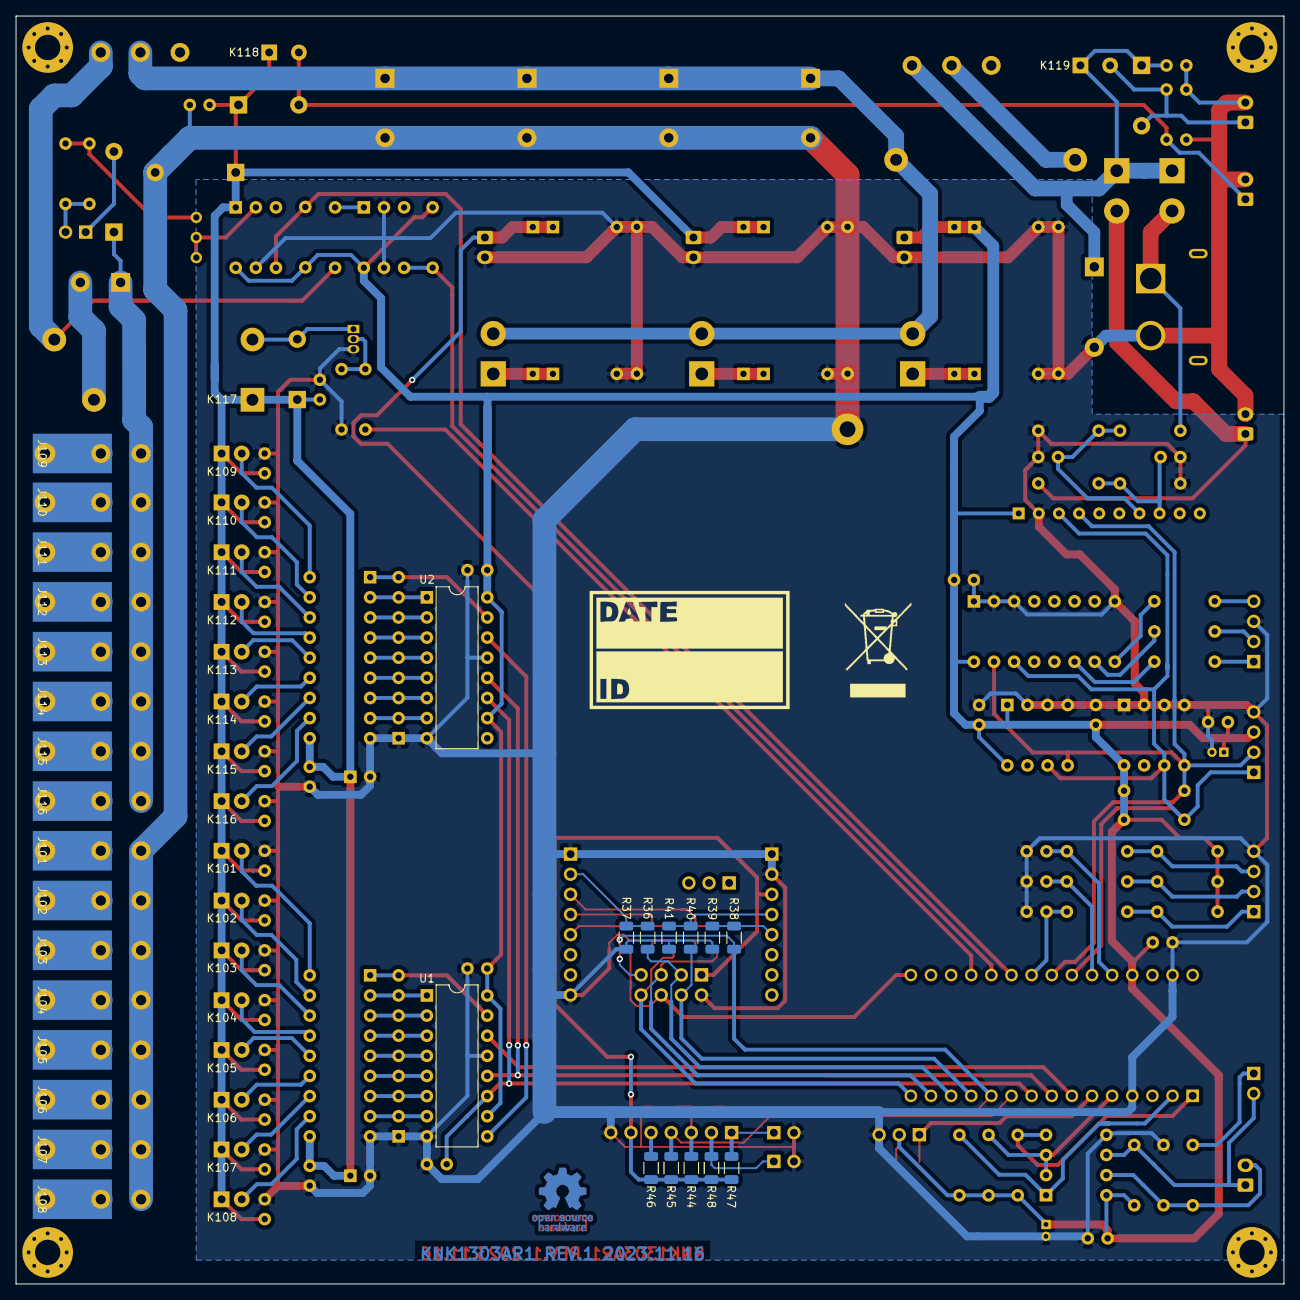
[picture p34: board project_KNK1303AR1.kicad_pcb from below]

Board: 2 copper layers, 160.0 x 160.0 mm, 196 parts (29 on the bottom side), 119 nets.

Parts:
A1: NANO_EVERY; Arduino_Nano
A2: ADS1115; pyrobox_module_ADC1115_mini
C1, C2, C3, C4, C6, C11, C12, C14, C15, C16, C17, C19, C20, C25, C101, C102, C103, C104, C105, C106, C107, C108, C109, C110, C111, C112, C113, C114, C115, C116, C117, C118, C125, C126, C127: 100n; C_Disc_D3.0mm_W2.0mm_P2.50mm
C5, C7: 22u; CP_Radial_D5.0mm_P2.50mm
C13, C18: 10u; CP_Radial_D4.0mm_P1.50mm
C21, C22: 150p; C_Disc_D3.0mm_W2.0mm_P2.50mm
C121, C122, C123, C124: 1K/50; CP_Radial_D16.0mm_P7.50mm
D101, D102: SB540; D_DO-201AD_P5.08mm_Vertical_KathodeUp
D103, D104, D111: 1N4148; D_DO-41_SOD81_P7.62mm_Horizontal
D105: BY550-1000; D_DO-27_P5.08mm_Vertical_KathodeUp
D106: 1N4002; D_DO-41_SOD81_P10.16mm_Horizontal
D107: 12V/1W; D_DO-41_SOD81_P10.16mm_Horizontal
D108, D109, D110: 1N5822; D_DO-201AD_P5.08mm_Vertical_KathodeUp
D112: P6KE33A; D_DO-15_P10.16mm_Horizontal
F101: 15A; Fuseholder_Cylinder-5x20mm_Stelvio-Kontek_PTF78_Horizontal_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
J1: 485; JST_XH_B2B-XH-A_1x02_P2.50mm_Vertical
J2: KEY_A; PinHeader_1x04_P2.54mm_Vertical
J4: LCD_A; PinHeader_1x04_P2.54mm_Vertical
J6: LED_A; PinHeader_1x04_P2.54mm_Vertical
J8: M0; PinHeader_1x02_P2.54mm_Vertical
J9: M1; PinHeader_1x02_P2.54mm_Vertical
J10: 120R; PinHeader_1x02_P2.54mm_Vertical
J11: NRF; PinSocket_2x04_P2.54mm_Vertical
J12: E32; PinSocket_1x07_P2.54mm_Vertical
J13: LORA_A; PinSocket_1x08_P2.54mm_Vertical
J14: LORA_B; PinSocket_1x08_P2.54mm_Vertical
J15: IRQ; PinSocket_1x03_P2.54mm_Vertical
J101: C11; SolderWirePad_1x01_SMD_5x10mm
J102: C12; SolderWirePad_1x01_SMD_5x10mm
J103: C13; SolderWirePad_1x01_SMD_5x10mm
J104: C14; SolderWirePad_1x01_SMD_5x10mm
J105: C21; SolderWirePad_1x01_SMD_5x10mm
J106: C22; SolderWirePad_1x01_SMD_5x10mm
J107: C23; SolderWirePad_1x01_SMD_5x10mm
J108: C24; SolderWirePad_1x01_SMD_5x10mm
J109: H11; SolderWirePad_1x01_SMD_5x10mm
J110: H12; SolderWirePad_1x01_SMD_5x10mm
J111: H13; SolderWirePad_1x01_SMD_5x10mm
J112: H14; SolderWirePad_1x01_SMD_5x10mm
J113: H21; SolderWirePad_1x01_SMD_5x10mm
J114: H22; SolderWirePad_1x01_SMD_5x10mm
J115: H23; SolderWirePad_1x01_SMD_5x10mm
J116: H24; SolderWirePad_1x01_SMD_5x10mm
J117: BATT_A; pyrobox_pcs_AMASS_XT60PW-M
J118: BATT2_A; JST_XH_B2B-XH-A_1x02_P2.50mm_Vertical
J119: PWR_A; JST_XH_B2B-XH-A_1x02_P2.50mm_Vertical
J121: ARM_A; JST_XH_B2B-XH-A_1x02_P2.50mm_Vertical
J123: +12V; JST_XH_B2B-XH-A_1x02_P2.50mm_Vertical
J124: +5V; JST_XH_B2B-XH-A_1x02_P2.50mm_Vertical
J126: +3V3; JST_XH_B2B-XH-A_1x02_P2.50mm_Vertical
J201: C11; Pin_D1.3mm_L10.0mm_W3.5mm_Flat
J202: C12; Pin_D1.3mm_L10.0mm_W3.5mm_Flat
J203: C13; Pin_D1.3mm_L10.0mm_W3.5mm_Flat
J204: C14; Pin_D1.3mm_L10.0mm_W3.5mm_Flat
J205: C21; Pin_D1.3mm_L10.0mm_W3.5mm_Flat
J206: C22; Pin_D1.3mm_L10.0mm_W3.5mm_Flat
J207: C23; Pin_D1.3mm_L10.0mm_W3.5mm_Flat
J208: C24; Pin_D1.3mm_L10.0mm_W3.5mm_Flat
J209: H11; Pin_D1.3mm_L10.0mm_W3.5mm_Flat
J210: H12; Pin_D1.3mm_L10.0mm_W3.5mm_Flat
J211: H13; Pin_D1.3mm_L10.0mm_W3.5mm_Flat
J212: H14; Pin_D1.3mm_L10.0mm_W3.5mm_Flat
J213: H21; Pin_D1.3mm_L10.0mm_W3.5mm_Flat
J214: H22; Pin_D1.3mm_L10.0mm_W3.5mm_Flat
J215: H23; Pin_D1.3mm_L10.0mm_W3.5mm_Flat
J216: H24; Pin_D1.3mm_L10.0mm_W3.5mm_Flat
JP101: 8mA; PinHeader_1x02_P2.54mm_Vertical
K101, K102, K103, K104, K105, K106, K107, K108, K109, K110, K111, K112, K113, K114, K115, K116: AZ921; pyrobox_pcs_ZETTLER_AZ921_vertical
K117: AZDC110; pyrobox_pcs_ZETTLER_AZDC110
K118, K119: 34.51; Relay_SPDT_Finder_34.51_Vertical
Q3: BC547; TO-92_Inline
R4, R6, R7, R9, R10, R11: 10K; R_Axial_DIN0207_L6.3mm_D2.5mm_P7.62mm_Horizontal
R5, R8, R17, R19, R20, R21: 4K7; R_Axial_DIN0207_L6.3mm_D2.5mm_P7.62mm_Horizontal
R12, R14: 15K/1%; R_Axial_DIN0207_L6.3mm_D2.5mm_P7.62mm_Horizontal
R13, R15: 3K/1%; R_Axial_DIN0207_L6.3mm_D2.5mm_P7.62mm_Horizontal
R18, R29: 120R; R_Axial_DIN0207_L6.3mm_D2.5mm_P7.62mm_Horizontal
R22, R23, R24: 100R; R_Axial_DIN0207_L6.3mm_D2.5mm_P7.62mm_Horizontal
R26, R44, R45, R46, R47, R48: 4K7; R_1206_3216Metric
R27: 200R; R_Axial_DIN0207_L6.3mm_D2.5mm_P7.62mm_Horizontal
R28: 180R; R_Axial_DIN0207_L6.3mm_D2.5mm_P7.62mm_Horizontal
R30, R32, R34, R36, R38, R40, R42: 220R; R_1206_3216Metric
R31, R33, R35, R37, R39, R41, R43: 470R; R_1206_3216Metric
R101, R102: 2K2; R_Axial_DIN0207_L6.3mm_D2.5mm_P7.62mm_Horizontal
R103, R106: 270R; R_Axial_DIN0207_L6.3mm_D2.5mm_P7.62mm_Horizontal
R104: 2K4; R_Axial_DIN0207_L6.3mm_D2.5mm_P7.62mm_Horizontal
RN1, RN2: 1K; R_Array_SIP9
RV101: 1K; zk_Bourns_3386C_Horizontal
U1, U2: 74HC595; DIP-16_W7.62mm
U3, U4: ULN2803A; DIP-18_W7.62mm
U5: PCF8574A; DIP-16_W7.62mm
U7, U10: 24LC256; DIP-8_W7.62mm
U8: MAX485EPA+; DIP-8_W7.62mm
U101, U102: H11L3; DIP-6_W7.62mm
U103: MP1584_12V; pyrobox_module_MP1584EN_2
U104: MP1584_5V; pyrobox_module_MP1584EN_2
U105: MP1584_3V3; pyrobox_module_MP1584EN_2

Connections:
+3V3: J11.1, J12.6, J13.3, J126.1, R44.2, R45.2, R46.2, R47.2, R48.2, U105.3
+5V: A1.27, A2.1, C1.1, C2.1, C3.1, C11.1, C12.1, C13.1, C18.1, C19.1, C20.1, C25.1, J4.3, J15.2, J124.1, R6.1, R7.2, R8.2, R9.2, R10.2, R11.2, R19.1, R20.2, R21.2, R26.2, R103.2, R106.2, U1.10, U1.16, U2.10, U2.16, U5.16, U7.8, U8.8, U10.1, U10.8, U101.6, U102.6, U104.3
+12V: C4.1, C5.1, C6.1, C7.1, C101.2, C102.2, C103.2, C104.2, C105.2, C106.2, C107.2, C108.2, C109.2, C110.2, C111.2, C112.2, C113.2, C114.2, C115.2, C116.2, C117.2, C118.2, D104.1, D107.1, D111.1, J123.1, K101.A1, K102.A1, K103.A1, K104.A1, K105.A1, K106.A1, K107.A1, K108.A1, K109.A1, K110.A1, K111.A1, K112.A1, K113.A1, K114.A1, K115.A1, K116.A1, K117.A1, K118.A1, U3.10, U4.10, U101.1, U103.3
/sheet_KNK1303AR1_01/485_DIR: A1.5, R8.1, U8.2, U8.3
/sheet_KNK1303AR1_01/485_RX: A1.2, R20.1, U8.1
/sheet_KNK1303AR1_01/485_TX: A1.1, R21.1, U8.4
/sheet_KNK1303AR1_01/595_CLOCK: A1.9, C17.1, U1.11, U2.11
/sheet_KNK1303AR1_01/595_DATA: A1.7, U1.14
/sheet_KNK1303AR1_01/595_LATCH: A1.8, U1.12, U2.12
/sheet_KNK1303AR1_01/I2C_SCL: A1.24, A2.3, J4.1, R7.1, U5.14, U7.6, U10.6
/sheet_KNK1303AR1_01/I2C_SDA: A1.23, A2.4, J4.2, R6.2, U5.15, U7.5, U10.5
/sheet_KNK1303AR1_01/INT0: A1.6, J15.1, R26.1
/sheet_KNK1303AR1_01/OUT_FR: A1.19, R4.1
/sheet_KNK1303AR1_01/SPI_CE: A1.12, J11.4, R40.1
/sheet_KNK1303AR1_01/SPI_CS: A1.13, J11.3, R36.1
/sheet_KNK1303AR1_01/SPI_IRQ: A1.11, J11.7, R38.1, R42.1
/sheet_KNK1303AR1_01/SPI_MISO: A1.15, J11.8, R32.1
/sheet_KNK1303AR1_01/SPI_MOSI: A1.14, J11.5, R34.1
/sheet_KNK1303AR1_01/SPI_NC: A1.10, J12.4, R45.1
/sheet_KNK1303AR1_01/SPI_SCK: A1.16, J11.6, R30.1
/sheet_KNK1303AR1_01/SW_MENU: A1.22, C16.1, R22.1
/sheet_KNK1303AR1_01/SW_NEXT: A1.25, C15.1, R23.1
/sheet_KNK1303AR1_01/SW_SET: A1.26, C14.1, R24.1
/sheet_KNK1303AR1_02/PWR_25: C121.1, C122.1, C123.1, C124.1, D108.2, D109.2, D110.2, F101.1, K118.11
GND: A1.4, A1.29, A2.2, C1.2, C2.2, C3.2, C4.2, C5.2, C6.2, C7.2, C11.2, C12.2, C13.2, C14.2, C15.2, C16.2, C17.2, C18.2, C19.2, C20.2, C21.2, C22.2, C25.2, C101.1, C102.1, C103.1, C104.1, C105.1, C106.1, C107.1, C108.1, C109.1, C110.1, C111.1, C112.1, C113.1, C114.1, C115.1, C116.1, C117.1, C118.1, C121.2, C122.2, C123.2, C124.2, C125.1, C126.2, C127.2, D107.2, D112.2, J2.4, J4.4, J6.3, J8.2, J9.2, J11.2, J12.7, J13.1, J13.2, J14.1, J14.8, J15.3, J117.2, J118.2, J119.2, J121.2, J123.2, J124.2, J126.2, K101.11, K102.11, K103.11, K104.11, K105.11, K106.11, K107.11, K108.11, Q3.3, R5.1, R13.1, R15.1, R17.1, R31.1, R33.1, R35.1, R37.1, R39.1, R41.1, R43.1, RN1.1, RN2.1, U1.8, U1.13, U2.8, U2.13, U3.9, U4.9, U5.1, U5.2, U5.3, U5.8, U7.1, U7.2, U7.3, U7.4, U8.5, U10.2, U10.3, U10.4, U101.5, U102.2, U102.5, U103.2, U103.4, U104.2, U104.4, U105.2, U105.4
IN_ARM: A1.20, R106.1, U102.4
IN_PWR1: D101.2, J117.1, R14.2
IN_PWR2: D102.2, J118.1, R12.1
IN_TEST: A1.21, R103.1, U101.4
unnamed: A2.7, C21.1, R14.1, R15.2
unnamed: A2.8, C22.1, R12.2, R13.2
unnamed: C125.2, D101.1, D102.1, D103.1, D112.1, K119.14, K119.A1
unnamed: C126.1, D103.2, J119.1, K119.A2
unnamed: C127.1, D104.2, J121.1, K118.A2
unnamed: D105.1, D106.1, K109.11, K110.11, K111.11, K112.11, K113.11, K114.11, K115.11, K116.11
unnamed: D105.2, K117.11
unnamed: D106.2, JP101.1
unnamed: D108.1, U103.1
unnamed: D109.1, U104.1
unnamed: D110.1, U105.1
unnamed: F101.2, K119.11
unnamed: J1.1, J10.2, R19.2, U8.6
unnamed: J1.2, R17.2, R18.1, U8.7
unnamed: J2.1, R9.1, R22.2
unnamed: J2.2, R10.1, R23.2
unnamed: J2.3, R11.1, R24.2
unnamed: J6.1, R27.1
unnamed: J6.2, R28.1
unnamed: J6.4, R29.1
unnamed: J10.1, R18.2
unnamed: J8.1, J12.1, R47.1
unnamed: J9.1, J12.2, R48.1
unnamed: J12.3, R42.2, R43.2, R44.1
unnamed: J12.5, R46.1
unnamed: J13.4, R40.2, R41.2
unnamed: J13.5, R38.2, R39.2
unnamed: J14.2, R36.2, R37.2
unnamed: J14.3, R34.2, R35.2
unnamed: J14.4, R32.2, R33.2
unnamed: J14.5, R30.2, R31.2
unnamed: J101.1, J201.1, K101.14
unnamed: J102.1, J202.1, K102.14
unnamed: J103.1, J203.1, K103.14
unnamed: J104.1, J204.1, K104.14
unnamed: J105.1, J205.1, K105.14
unnamed: J106.1, J206.1, K106.14
unnamed: J107.1, J207.1, K107.14
unnamed: J108.1, J208.1, K108.14
unnamed: J109.1, J209.1, K109.14
unnamed: J110.1, J210.1, K110.14
unnamed: J111.1, J211.1, K111.14
unnamed: J112.1, J212.1, K112.14
unnamed: J113.1, J213.1, K113.14
unnamed: J114.1, J214.1, K114.14
unnamed: J115.1, J215.1, K115.14
unnamed: J116.1, J216.1, K116.14
unnamed: JP101.2, R101.1, R102.1
unnamed: K117.14, K118.14, R104.1
unnamed: Q3.2, R4.2, R5.2
unnamed: R27.2, U5.11
unnamed: R28.2, U5.10
unnamed: R29.2, U5.9
unnamed: R101.2, R102.2, RV101.1
unnamed: R104.2, U102.1
unnamed: RN1.2, U1.7, U3.8
unnamed: RN1.3, U1.6, U3.7
unnamed: RN1.4, U1.5, U3.6
unnamed: RN1.5, U1.4, U3.5
unnamed: RN1.6, U1.3, U3.4
unnamed: RN1.7, U1.2, U3.3
unnamed: RN1.8, U1.1, U3.2
unnamed: RN1.9, U1.15, U3.1
unnamed: RN2.2, U2.7, U4.8
unnamed: RN2.3, U2.6, U4.7
unnamed: RN2.4, U2.5, U4.6
unnamed: RN2.5, U2.4, U4.5
unnamed: RN2.6, U2.3, U4.4
unnamed: RN2.7, U2.2, U4.3
unnamed: RN2.8, U2.1, U4.2
unnamed: RN2.9, U2.15, U4.1
unnamed: RV101.2, RV101.3, U101.2
unnamed: U1.9, U2.14
OUT_C11: K101.A2, U3.18
OUT_C12: K102.A2, U3.17
OUT_C13: K103.A2, U3.16
OUT_C14: K104.A2, U3.15
OUT_C21: K105.A2, U3.14
OUT_C22: K106.A2, U3.13
OUT_C23: K107.A2, U3.12
OUT_C24: K108.A2, U3.11
OUT_FIRE: D111.2, K117.A2, Q3.1
OUT_H11: K109.A2, U4.18
OUT_H12: K110.A2, U4.17
OUT_H13: K111.A2, U4.16
OUT_H14: K112.A2, U4.15
OUT_H21: K113.A2, U4.14
OUT_H22: K114.A2, U4.13
OUT_H23: K115.A2, U4.12
OUT_H24: K116.A2, U4.11

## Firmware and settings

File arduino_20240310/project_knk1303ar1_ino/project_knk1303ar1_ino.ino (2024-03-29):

/* KNK1303AR1 rev.1 | FirstStep Firing System | https://forumfajerwerki.pl
 * file: project_knk1303ar1_ino.ino | date: 2023.12.14
 *
 * Arduino IDE Version 2.3.2
 * board: "Arduino Nano Every" | registers emulation: "NONE (ATMEGA4809)"
 *
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
 * THIS SOFTWARE IS PROVIDED BY THE COPYRIGHT HOLDERS AND CONTRIBUTORS "AS IS" AND 
 * ANY EXPRESS OR IMPLIED WARRANTIES, INCLUDING, BUT NOT LIMITED TO, THE IMPLIED 
 * WARRANTIES OF MERCHANTABILITY AND FITNESS FOR A PARTICULAR PURPOSE ARE DISCLAIMED. 
 * IN NO EVENT SHALL THE COPYRIGHT HOLDER OR CONTRIBUTORS BE LIABLE FOR ANY DIRECT, 
 * INDIRECT, INCIDENTAL, SPECIAL, EXEMPLARY, OR CONSEQUENTIAL DAMAGES (INCLUDING, 
 * BUT NOT LIMITED TO, PROCUREMENT OF SUBSTITUTE GOODS OR SERVICES; LOSS OF USE, DATA, 
 * OR PROFITS; OR BUSINESS INTERRUPTION) HOWEVER CAUSED AND ON ANY THEORY OF LIABILITY, 
 * WHETHER IN CONTRACT, STRICT LIABILITY, OR TORT (INCLUDING NEGLIGENCE OR OTHERWISE) 
 * ARISING IN ANY WAY OUT OF THE USE OF THIS SOFTWARE, EVEN IF ADVISED OF THE POSSIBILITY 
 * OF SUCH DAMAGE.  
 */

/*==========1==========2==========3==========4==========5==========6==========7==========*/
#include <Arduino.h>
#include <Wire.h>
#include <CRC16.h>
#include <EEPROM.h>
#include "headerfile.hpp" 
#include "unit_var.hpp" //pin declarations -> unit_var.hpp/cpp //pinout -> unit_var.cpp 

/*---------------------------------------------------------------------------------------*/
#include "LiquidCrystal_PCF8574.h" //https://github.com/mathertel/LiquidCrystal_PCF8574
LiquidCrystal_PCF8574 lcd( 0x27);  //addr=0x27 => i2c->HD44750 

/*---------------------------------------------------------------------------------------*/
#include "PCF8574.h" //https://github.com/xreef/PCF8574_library
PCF8574 led( 0x38);  //addr=0x20(..0x27) => PCF8574 | addr=0x38(..0x3F) => PCF8574A

/*---------------------------------------------------------------------------------------*/
#include <Toggle.h> //https://github.com/Dlloydev/Toggle/tree/main //-> buttons

/*---------------------------------------------------------------------------------------*/
#include <avr/wdt.h> //-> watchdog

/*---------------------------------------------------------------------------------------*/
//#include <ADS1115_WE.h> //https://github.com/wollewald/ADS1115_WE
//ADS1115_WE adc = ADS1115_WE( 0x48); //addr=0x48 => ADS1115 <- unit_ads1115.cpp

/*========== TIMERS =====================================================================*/
//zapalanie lcd na 10sec po nacisniecia przycisku

boolean bTimerLcd = false;
unsigned long iStartTimeLcd = 0; //local var

void time_LCDstart() { iStartTimeLcd = millis(); bTimerLcd = true; } //timerLCD start 
void time_LCDstop() { bTimerLcd = false; lcd.noDisplay(); lcd.setBacklight( 0); } //stop -> lcd off
//loop: if( bTimerLcd == true) { if( millis() - iStartTimeLcd >= 10000) time_LCDstop(); }

/*---------------------------------------------------------------------------------------*/
//usuniecie z lcd znaku heartbeat po 500msec od wyswietlenia

boolean bTimerXP = false;
unsigned long iStartTimeXP = 0; //local var

void led_show( byte i);

void time_XPstart() { iStartTimeXP = millis(); bTimerXP = true; } //timerXP start 
void time_XPstop() { bTimerXP = false; lcd.setCursor( 15, 1);  lcd.print( " "); //stop -> heartbeat char clear
                     int n = EEPROM.read( 3); led_show( n); } //n = iArm=iArmH+iArmS //led_blue_off
//loop: if( bTimerXP == true) { if( millis() - iStartTimeXP >= 500) time_XPstop(); }
//cmd_XP(): led_show( 4); //led_blue_on

/*---------------------------------------------------------------------------------------*/
//wyswietlenie na lcd info link.err po 500msec bez odpowiedzi master

boolean bTimerYX = false;
unsigned long iStartTimeYX = 0; //local var

void time_YXstart() { iStartTimeYX = millis(); bTimerYX = true; } //timerYX start
void time_YXstop() { bTimerYX = false; lcd.setCursor( 6, 1); lcd.print( F( "LINK ERROR")); } //stop -> link.err
//loop: if( bTimerYX == true) { if( millis() - iStartTimeYX >= 500) time_YXstop(); } 

/*========== LCD_I2C ====================================================================*/
byte heartbeat[] = { 0b11111, 0b10001, 0b10101, 0b10101, 0b10101, 0b10101, 0b10001, 0b11111 }; //heartbeat
extern char hAdr[11]; //(set_setup.cpp)

void lcd_begin() {
  lcd.begin( 16, 2);
  lcd.setBacklight( 64); //max 255
  lcd.createChar(1, heartbeat); //znak specjalny hb
  lcd.home();
  lcd.noCursor(); 
  lcd.clear();
  lcd.setCursor( 0, 0); lcd.print( F("ADDR:           ")); //"ADDR:           " //line_1
  lcd.setCursor( 6, 0); lcd.print( String(hAdr));          //      "16.16/4.13" //line_1
  //lcd_lightOff(); //wlacza wygaszanie lcd
}

void lcd_lightOff() { time_LCDstart(); } //wygaszenie lcd po 10sec
void lcd_lightOn()  { time_LCDstart(); lcd.display(); lcd.setBacklight( 64); } //podswietlenie lcd na 10sec

/*========== LED_I2C ====================================================================*/
void led_begin() {
  led.pinMode(P4, OUTPUT, LOW); //led_blue
	led.pinMode(P5, OUTPUT, LOW); //led_green
	led.pinMode(P6, OUTPUT, LOW); //led_red
	led.pinMode(P7, OUTPUT, LOW); //buzzer
  led.begin();
}

void led_show( byte i) { //0..3 plus 4=blue
  switch ( i) {        //led:red                         green                       blue
    case 0: led.digitalWrite(P6, LOW);  led.digitalWrite(P5, HIGH); led.digitalWrite(P4, LOW);  break; //green  //arm.safe
    case 1: led.digitalWrite(P6, HIGH); led.digitalWrite(P5, HIGH); led.digitalWrite(P4, LOW);  break; //yellow //arm.hard_on
    case 2: led.digitalWrite(P6, HIGH); led.digitalWrite(P5, HIGH); led.digitalWrite(P4, LOW);  break; //yellow //arm.soft_on
    case 3: led.digitalWrite(P6, HIGH); led.digitalWrite(P5, LOW);  led.digitalWrite(P4, LOW);  break; //red    //arm.armed
    case 4: led.digitalWrite(P6, LOW);  led.digitalWrite(P5, LOW);  led.digitalWrite(P4, HIGH); break; //blue   //heartbeat
   }
}

void led_buzzer() { led.digitalWrite(P7, HIGH); myDelay( 1000); led.digitalWrite(P7, LOW); } //nie uzywane

/*========== BUTTONS ====================================================================*/
const byte pin_buttonMenu  = A3; //17
const byte pin_buttonClear = A6; //20
const byte pin_buttonLink  = A7; //21
const byte pin_inArm       = A1; //15

Toggle sw1( pin_buttonMenu);  //button_MENU
Toggle sw2( pin_buttonClear); //button_NEXT/CLEAR
Toggle sw3( pin_buttonLink);  //button_SET/LINK
Toggle sw4( pin_inArm);       //key_ARM


/*****************************************************************************************/
/*========== SETUP_START                                                       ==========*/
/*****************************************************************************************/

void(* resetFunc) (void) = 0; //soft reset
void resetModule() { resetFunc(); } //przekazanie do cpp

/*---------------------------------------------------------------------------------------*/
void setup() { //!!! nie zmieniac kolejnosci wywolan funkcji
  //----------CONFIG
  pinSetup(); //pins alliances
  setup_readSetup(); //read/set: idno+user+addr+info+arm
  //----------SERIALS
  Serial. begin( 9600); //usb_terminal
  Serial1.begin( 9600); //rs485
  Wire.begin(); delay( 5); //i2c_100kHz 
  //----------INTERFACE
  lcd_begin(); //lcd
  led_begin(); //led
  //--buttons 
  sw1.begin( pin_buttonMenu);
  sw2.begin( pin_buttonClear);
  sw3.begin( pin_buttonLink);
  sw4.begin( pin_inArm);
  //----------OTHERS
  knk1303ar1_outputReset(); //74595 reset
  ads1115_setup(); //adc_pwr1/pwr2
  //lora32_setup();
  //----------WATCHDOG
  wdt_enable(WDT_PERIOD_512CLK_gc);
}
/*
typedef enum WDT_PERIOD_enum {
WDT_PERIOD_OFF_gc    = (0x00<<0), / Off /
WDT_PERIOD_8CLK_gc   = (0x01<<0), / 8 cycles (8ms) /
WDT_PERIOD_16CLK_gc  = (0x02<<0), / 16 cycles (16ms) /
WDT_PERIOD_32CLK_gc  = (0x03<<0), / 32 cycles (32ms) /
WDT_PERIOD_64CLK_gc  = (0x04<<0), / 64 cycles (64ms) /
WDT_PERIOD_128CLK_gc = (0x05<<0), / 128 cycles (0.128s) /
WDT_PERIOD_256CLK_gc = (0x06<<0), / 256 cycles (0.256s) /
WDT_PERIOD_512CLK_gc = (0x07<<0), / 512 cycles (0.512s) /
WDT_PERIOD_1KCLK_gc  = (0x08<<0), / 1K cycles (1.0s) /
WDT_PERIOD_2KCLK_gc  = (0x09<<0), / 2K cycles (2.0s) /
WDT_PERIOD_4KCLK_gc  = (0x0A<<0), / 4K cycles (4.1s) /
WDT_PERIOD_8KCLK_gc  = (0x0B<<0), / 8K cycles (8.2s) /
} WDT_PERIOD_t;
*/

/*****************************************************************************************/
/*========== SETUP_STOP                                                        ==========*/
/*****************************************************************************************/


/*****************************************************************************************/
/*========== LOOP_START                                                        ==========*/
/*****************************************************************************************/

boolean comenabled = true; //rs485 flag true=open/false=close
char hDataBuffer[47]; //rs485 buffer <= cmd_PD_answer={1<crc>4<PD>2<inf>4<pwr>6<ser>9<usr>9<add>6<ant>3<arm>1}1=46+1
char hUsbBuffer[4] = {'G','0','1','\0'}; //usb_terminal buffer

//extern char hCmdFTbuffer[8];  
//-> cmd_FT //{'&','0','0','0','0','2','&','\0'} 
//extern char hCmdFAbuffer[24]; 
//-> cmd_FA //{'$','5','0','0','1','0','B','4','F','H','0','0','0','3','3','3','0','5','1','0','0','1','$','\0'}
//extern char hCmdSAMbuffer[26]; //cmdFH=20-2{}+3@,@+5time

/*---------------------------------------------------------------------------------------*/
void loop() {
  //----------TIMERS
  if( bTimerXP  == true) { if( millis() - iStartTimeXP  >=   500) time_XPstop(); }  //cmd_XP
  if( bTimerYX  == true) { if( millis() - iStartTimeYX  >=   500) time_YXstop(); }  //cmd_YX
  if( bTimerLcd == true) { if( millis() - iStartTimeLcd >= 10000) time_LCDstop(); } //lcd_on/off

  //----------BUTTONS //!!! odblokowac lcd_lightOn() !!!
  sw1.poll(); if( sw1.onPress()) { /*lcd_lightOn();*/ menu_buttonMenu(); }  //wlacza lcd przy aktywnym wygaszaniu
  sw2.poll(); if( sw2.onPress()) { /*lcd_lightOn();*/ menu_buttonClear(); }
  sw3.poll(); if( sw3.onPress()) { /*lcd_lightOn();*/ menu_buttonLink(); }
  sw4.poll(); if( sw4.isPressed()) { key_On(); }  //key_arm_on
                else               { key_Off(); } //key_arm_off 

  //----------RS485
  if( comenabled == true) { //mozna korzystac z rs485, port dostepny
    if( Serial1.available()) { 
      char z = Serial1.read(); //pobieramy pierwszy znak 
      //----------CMD_
      if( z == '{') { //sprawdzamy czy to { ('&'=sdf '$'=asu '@'=sam)
        String sCmd = Serial1.readStringUntil( '}'); //pobieramy reszte do }
        comenabled = false; //zamykamy port
        //--bufor roboczy hDataBuffer
        sCmd = '{' + sCmd + '}'; //dodajemy terminator { bo zostal pominiety oraz } bo readStringUntil go obcial
        int iCmd = sCmd.length() + 1;
        sCmd.toCharArray( hDataBuffer, iCmd); //przenosimy cmd do bufora roboczego
        //Serial.print( "RX:"); Serial.println( hDataBuffer); //<=== !!! TEST !!! //usunac, takze w rs485_print()
        //--kalkulacja crc
        char hCrc[5]; //bufor na crc z cmd
        for( int i = 0; i <= 3; i++) { hCrc[i] = hDataBuffer[i + 1]; } //pobieramy crc
        char hTmp[iCmd - 6]; //tworzymy bufor tmp do kalkulacji crc, -6 bo {1 + <crc>4 + }1 
        for( int i = 0; i < (sizeof(hTmp) / sizeof(hTmp[0]) - 1); i++) { hTmp[i] = hDataBuffer[i + 5]; } //pobieramy dane bez crc
        CRC16 tmpcrc;
        tmpcrc.setPolynome( 0x1021); //CRC-CCITT
        for( int i = 0; i < (sizeof(hTmp) / sizeof(hTmp[0]) - 1); i++) { tmpcrc.add( hTmp[i]); } //wczytujemy dane do tmpcrc
        uint16_t itmpcrc = tmpcrc.getCRC(); //kalkulujemy crc
        char htmpcrc[5]; sprintf( htmpcrc, "%04X", itmpcrc); //przeksztalacamy crc int na crc hex
        //--porownanie crc
        if((htmpcrc[0] == hCrc[0]) && (htmpcrc[1] == hCrc[1]) && (htmpcrc[2] == hCrc[2]) && (htmpcrc[3] == hCrc[3])) { 
          data_runCmd(); //przekazanie cmd do analizy
        }
        comenabled = true; //udostepniamy port
      } //end if z={
    
      //----------CMD_FT__SDF.sft
      else if( z == '&') {
        String sSdf = Serial1.readStringUntil( '&'); 
        comenabled = false; 
        sSdf = '&' + sSdf + '&';
        //sSdf.toCharArray( hCmdFTbuffer, sSdf.length() + 1);
        //Serial.print( "RX:"); Serial.println( hCmdFTbuffer); //<=== !!! TEST !!!
        //cmd_FTeepWrite();
        comenabled = true;
      }

      //----------CMD_FA__ASU.sfa   
      else if( z == '$') {
        String sAsu = Serial1.readStringUntil( '$'); 
        comenabled = false; 
        sAsu = '$' + sAsu + '$'; 
        //sAsu.toCharArray( hCmdFAbuffer, sAsu.length() + 1); 
        //Serial.print( "RX:"); Serial.println( hCmdFAbuffer); //<=== !!! TEST !!!
        //cmd_FAeepWrite();
        comenabled = true;
      }

      //----------CMD_SAM__SAM.sam  
      else if( z == '@') {
        String sSam = Serial1.readStringUntil( '@'); 
        comenabled = false; 
        sSam = '@' + sSam + '@'; 
        //sAsu.toCharArray( hCmdSAMbuffer, sSam.length() + 1); 
        //Serial.print( "RX:"); Serial.println( hCmdSAMbuffer); //<=== !!! TEST !!!
        //cmd_SAMeepWrite();
        comenabled = true;
      }

      //----------LoRa_E32TTL100
      //lora32_loop();

    } //end if Serial1.available
  } //end if comenabled=true

  //----------USB_TERMINAL
  if( Serial.available()) {
    char u = Serial.read(); 
    //-----PRESET
    if(  u == 'q') { setup_default(); } //factory preset
    if( (u == 'G') || (u == 'U') || (u == 'M') || (u == 'S')) { //grp/unt/mod/sec preset <- G01..16
      hUsbBuffer[0] = u; 
      int n = 1;
      while( Serial.available()) { u = Serial.read(); hUsbBuffer[n] = u; n++; }
      hUsbBuffer[3] = '\0';
      usb_dataRead();
      Serial.println( hUsbBuffer); //usb_terminal
    }
    //-----TEST
    if(  u == 'i') service_i2cScanner(); //i2c device scanner
   }
  
  //----------LOOP_END
  wdt_reset(); //watchdog reset
  delay( 1);   //delay 1msec
}

/*****************************************************************************************/
/*========== LOOP_STOP                                                         ==========*/
/*****************************************************************************************/

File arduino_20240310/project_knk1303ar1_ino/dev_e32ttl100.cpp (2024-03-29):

/* KNK1303AR1 rev.1 | FirstStep Firing System | https://forumfajerwerki.pl
 * file: dev_e32ttl100.cpp | date: 2023.10.27 //!!! nie testowane
 */
/*==========1==========2==========3==========4==========5==========6==========7==========*/
/*
public:
void lora32_setup();
void lora32_loop();
*/
#include <Arduino.h>
#include "headerfile.hpp"
#include "unit_var.hpp"
/*
E32-TTL-100 -> nano every
1.M0  -> GND
2.M1  -> GND
3.TX  -> D7 (PullUP 4,7KΩ)
4.RX  -> D2 (PullUP 4,7KΩ & Voltage divider)
5.AUX -> not connected
6.VCC -> 3.3v
7.GND -> GND
*/
/*================================================================================#1=====*/
/*
#include <SoftwareSerial.h>
SoftwareSerial mySerial( 7, 8); //rxPin=7 txPin=8 ===> e32_TX e32_RX

void lora32_setup() {
  mySerial.begin( 9600);
}
*/ 
/*---------------------------------------------------------------------------------------*/
/*
void lora32_loop() {
  if( mySerial.available()) { 
    Serial.write( mySerial.read()); 
  }
  if( Serial.available()) { 
    mySerial.write( Serial.read()); 
  }
}
*/
/*================================================================================#2=====*/
//https://mischianti.org/lora-e32-device-for-arduino-esp32-or-esp8266-specs-and-basic-usage-part-1/

#include "LoRa_E32.h" //https://github.com/xreef/LoRa_E32_Series_Library

#include <SoftwareSerial.h>
SoftwareSerial mySerial( 7, 8); //rxPin=7 txPin=8 ===> e32_TX e32_RX
LoRa_E32 e32ttl100( &mySerial);

/*
select one:
#define E32_TTL_100
#define E32_TTL_500
#define E32_TTL_1W
select one:
#define FREQUENCY_433
#define FREQUENCY_170
#define FREQUENCY_470
#define FREQUENCY_868
#define FREQUENCY_915
*/
/* normal mode / transparent transmission: (arduino uno)
1.M0  -> GND (Set normal mode)
2.M1  -> GND (Set normal mode)
3.TX  -> PIN 2 (PullUP 4,7KΩ)
4.RX  -> PIN 3 (PullUP 4,7KΩ & Voltage divider)
5.AUX -> Not connected
6.VCC -> 3.3v
7.GND -> GND

For normal transmission, you must set M0 and M1 to LOW, 
and It’s better if you connect the AUX pin to have a better synchronization, but not needed. 
You can check the connection of the AUX pin in the library complete example connection, 
and you only must add the pin number to the constructor.

LoRa_E32 e32ttl100( 2, 3);    //TX, RX
LoRa_E32 e32ttl100( 2, 3, 5); //TX, RX, AUX
LoRa_E32 e32ttl100( 2, 3, 5, 7, 6); //with AUX and M0 M1
 
#include <SoftwareSerial.h>
SoftwareSerial mySerial( 2, 3);
LoRa_E32 e32ttl100( &mySerial, 5, 7, 6);
*/

void lora32_setup() {
  //startup all pins and UART
  e32ttl100.begin();
  //send message
  ResponseStatus rs = e32ttl100.sendMessage( "Hello, world?");
  //check if there is some problem of successfully send
  Serial.println( rs.getResponseDescription());
}
 
/*---------------------------------------------------------------------------------------*/
void lora32_loop() {
  //if something available
  if( e32ttl100.available()>1) {
    //read the String message
    ResponseContainer rc = e32ttl100.receiveMessage();
    //is something goes wrong print error
    if( rc.status.code!=1){
      rc.status.getResponseDescription();
    } else {
      //print the data received
      Serial.println( rc.data);
    }
  }
  if( Serial.available()) {
    String input = Serial.readString();
    e32ttl100.sendMessage( input);
  }
}

/*---------------------------------------------------------------------------------------*/
//if you have ever change configuration you must restore it
/*
  ResponseStructContainer c;
  c = e32ttl100.getConfiguration();
  Configuration configuration = *(Configuration*) c.data;
  Serial.println(c.status.getResponseDescription());
  configuration.CHAN = 0x17;
  configuration.OPTION.fixedTransmission = FT_TRANSPARENT_TRANSMISSION;
  e32ttl100.setConfiguration(configuration, WRITE_CFG_PWR_DWN_SAVE);
*/


/*================================================================================#3=====*/
//arduino uno -> e32ttl100 -> M0 M1 -> 3.3v
/*
LoRa_E32 e32ttl100( 2, 3);
void printParameters( struct Configuration configuration);
void printModuleInformation( struct ModuleInformation moduleInformation);
 
void setup() {
    Serial.begin(9600);
    delay(500);
 
    // Startup all pins and UART
    e32ttl100.begin();
 
    ResponseStructContainer c;
    c = e32ttl100.getConfiguration();
    // It's important get configuration pointer before all other operation
    Configuration configuration = *(Configuration*) c.data;
    Serial.println(c.status.getResponseDescription());
    Serial.println(c.status.code);
 
    printParameters(configuration);
    configuration.ADDL = 0x0;
    configuration.ADDH = 0x1;
    configuration.CHAN = 0x19;
 
    configuration.OPTION.fec = FEC_0_OFF;
    configuration.OPTION.fixedTransmission = FT_TRANSPARENT_TRANSMISSION;
    configuration.OPTION.ioDriveMode = IO_D_MODE_PUSH_PULLS_PULL_UPS;
    configuration.OPTION.transmissionPower = POWER_17;
    configuration.OPTION.wirelessWakeupTime = WAKE_UP_1250;
 
    configuration.SPED.airDataRate = AIR_DATA_RATE_011_48;
    configuration.SPED.uartBaudRate = UART_BPS_115200;
    configuration.SPED.uartParity = MODE_00_8N1;
 
    // Set configuration changed and set to not hold the configuration
    ResponseStatus rs = e32ttl100.setConfiguration(configuration, WRITE_CFG_PWR_DWN_LOSE);
    Serial.println(rs.getResponseDescription());
    Serial.println(rs.code);
    printParameters(configuration);
    c.close();
}
 
void loop() {}
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

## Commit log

2024-03-25 kicad_20240310 files added
    [project_KNK1303AR1.kicad_pcb, project_KNK1303AR1.kicad_sch, pyrobox_module_ADS1115.stp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]
2024-03-25 kicad_20240310.zip file added
2024-03-29 arduino_20240310.zip file added
2024-03-29 arduino_20240310 files added

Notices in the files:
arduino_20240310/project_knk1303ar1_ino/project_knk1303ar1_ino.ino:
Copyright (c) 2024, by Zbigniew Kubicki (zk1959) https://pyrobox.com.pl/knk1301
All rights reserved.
